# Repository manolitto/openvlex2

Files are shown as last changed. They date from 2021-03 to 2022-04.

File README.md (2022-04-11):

<p align="center">OpenVLex2 Showcase</p>
<h1 align="center">OpenVLex 2</h1>
<p align="center">A decor-to-base <b>V</b>ertical <b>L</b>ocking <b>ex</b>tension system for 3D printed terrain</p>
<p align="center">
  <a href="#about">About</a> •
  <a href="#download">Download</a> •
  <a href="#getting-started">Getting Started</a> •
  <a href="#faqs">FAQs</a> •
  <a href="#credits">Credits</a> •
  <a href="#license">License</a>
</p>

## About

OpenVLex makes it possible to print and use base and terrain parts more **flexibly** by providing a special vertical locking mechanism while still adhering to the widely used, well-established tile locking systems. You can use the same terrain decor piece with bases of different sizes or locking standards. Think OpenForge 2.0, but instead of gluing, you clip your terrain pieces to the base.  
For now, OpenVLex supports bases with **OpenLOCK (Triplex)** standard, and also the versatile **OpenForge Magnetic OpenLOCK** bases. Other locking systems (Dragonlock, Infinitylock) may be supported in the future.

OpenLOCK compatible

### What to expect

OpenVLex vertical locking can be used in many ways, but the most common use case is that you have versatile painted "wall on tile" (aka "wall on floor") terrain pieces that you want to reuse in multiple scenarios with different room sizes.

#### Key features:

- **Extend** the tile sets you already have. OpenVLex is **NOT yet another tile locking system**, but serves to make Magnetic/OpenLOCK tiles even more versatile.

- Magnetic bases are cool and handy, but not as versatile and not as solidly clipping together as Triplex parts: With OpenVLex you can **choose the right tile locking system "just in time"**.

- Large overhanging (upper) floors clipped together are not always as solid as they need to be. With OpenVLex you can build **rock solid upper floors** even with tiny 1x1 wall or corner pieces on up to 8x8 bases (or even larger if your printer is capable).

- With reusable OpenVLex magnetic bases, you need **much fewer magnetic balls** in total.

- OpenVLex **risers and stair parts** can be stacked and plugged together directly, giving you endless possibilities.

- OpenVLex gives you **dynamic floors out of the box**: each 1x1 floor tile can immediately be used for mosaics, patterned floors or as a scatter.

- With OpenVLex you can **re-use** your **wall-on-tile parts** (walls, floors, ...) on the **outside** of your dungeons or buildings without having ugly holes in the foundation.

- OpenVLex allows you to flexibly exchange the base of **"separate wall"** parts and make an **interior 1/2 inch** wide interior wall out of an exterior wall. This wall can be locked by using special 1/2 inch "through hole" clips.

- With a basic set of reusable bases in different sizes, you will never have to print a base again. **Save printing time and money**. And save plastic and rare earths (magnets). Save the planet! :earth_africa::earth_americas::earth_asia::nerd_face:

- OpenVLex is a non-commercial **open source** solution that I created in my spare time. Feel **free to use** it. No need to buy me a coffee or a beer, instead, just be a nice person and help people in need :relaxed:.  
  And please share your experiences with OpenVLex and give me feedback!

## Download

You can find the latest release [here](https://github.com/manolitto/openvlex2/releases/latest).

## Getting started

To give you an idea of how OpenVLex works and the advantages it offers, you can follow this guide:

1. Choose your favourite OpenForge 2.0 floor terrain set.  
   > If you are unsure, start with Devon Jones' well-known [OpenForge 2.0 Dungeon Stone Floor](https://www.thingiverse.com/thing:2740273)

2. Print **one** 1x1, **one** 2x2 and **four** 2x1 inch based (Dungeon Stone) floor parts.  
   Print only the decor parts without the OpenForge 2.0 bases!  
   > **Printing time:** ~3 hours at medium quality on a FFF printer
   
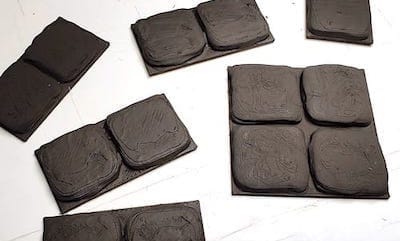
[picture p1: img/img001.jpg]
Floor tiles
   

3. Download [the latest version](https://github.com/manolitto/openvlex2/releases/latest) of OpenVLex 2 if you haven't already done so.

4. Print fourteen **[OpenVLex jacks](jacks/)**. See [jack printing details and hints](jacks/README.md).  
   > **Printing time:** < 40 mins
   
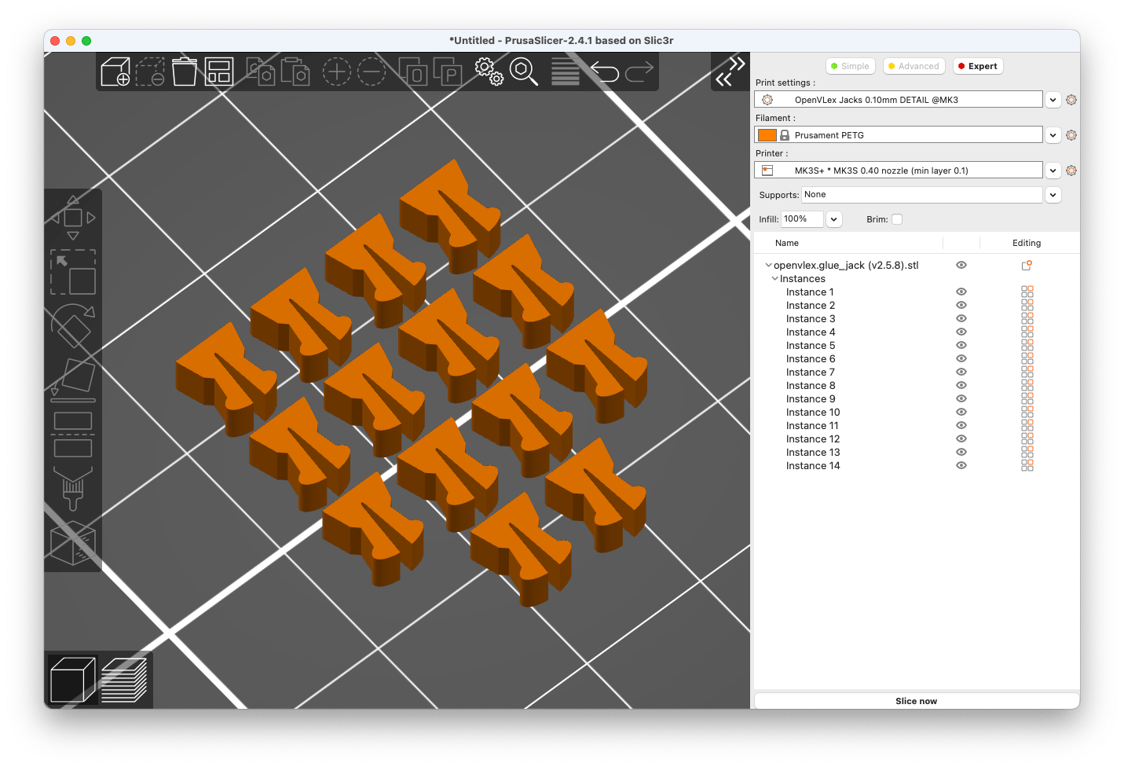
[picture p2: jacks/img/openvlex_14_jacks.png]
OpenVLex jacks
   

5. Glue the jacks to the floor parts. See [jack gluing instructions](jacks/README.md#gluing-instructions).  
   > **Note:** You only need thirteen jacks, one is a spare
   
   Either with a [gluing stencil](./gluing-stencil/README.md) (recommended)
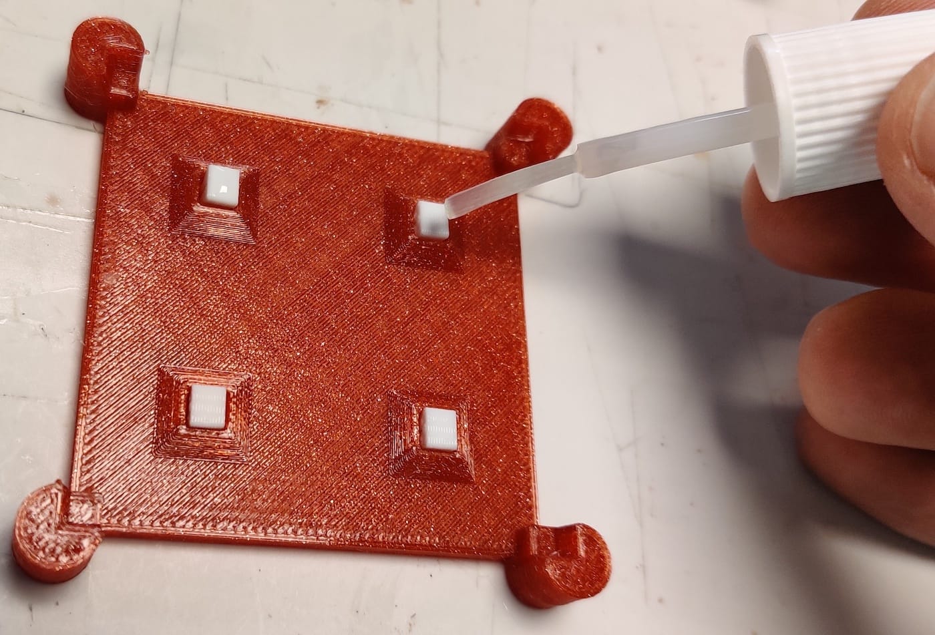
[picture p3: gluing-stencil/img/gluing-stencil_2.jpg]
   
   Or with an already printed [OpenVLex base](./bases/README.md)
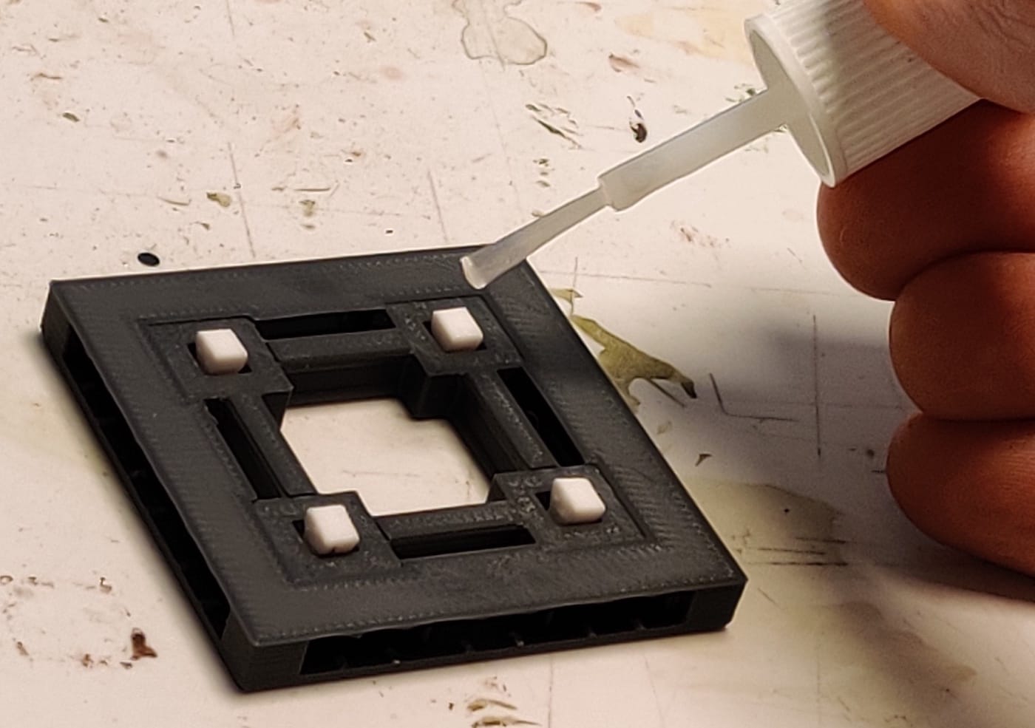
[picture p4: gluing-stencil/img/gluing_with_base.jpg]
   
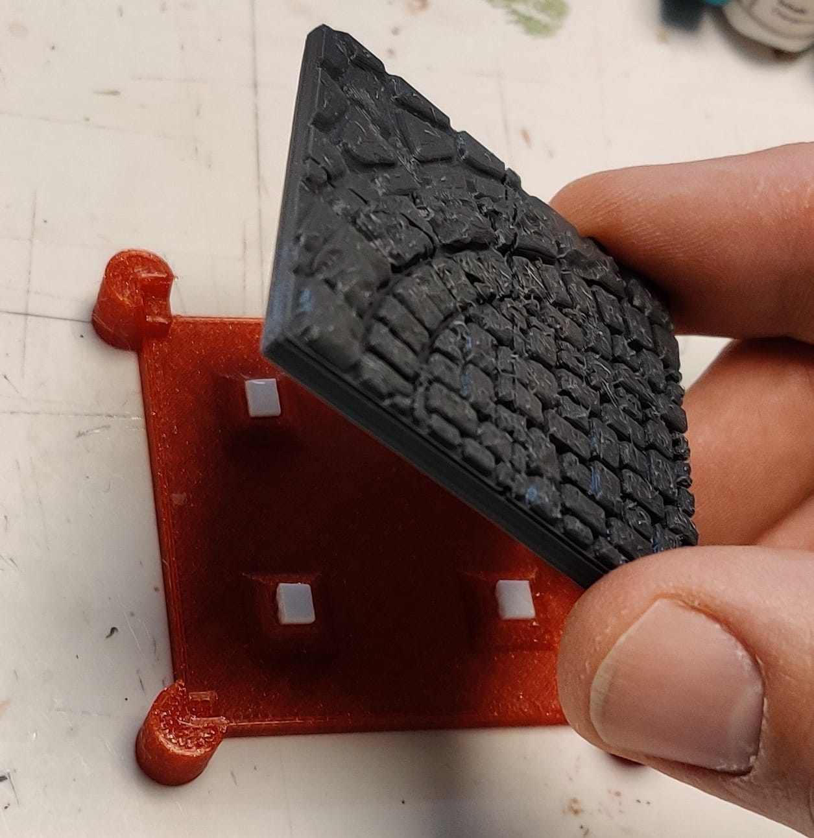
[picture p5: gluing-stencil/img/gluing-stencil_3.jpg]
     
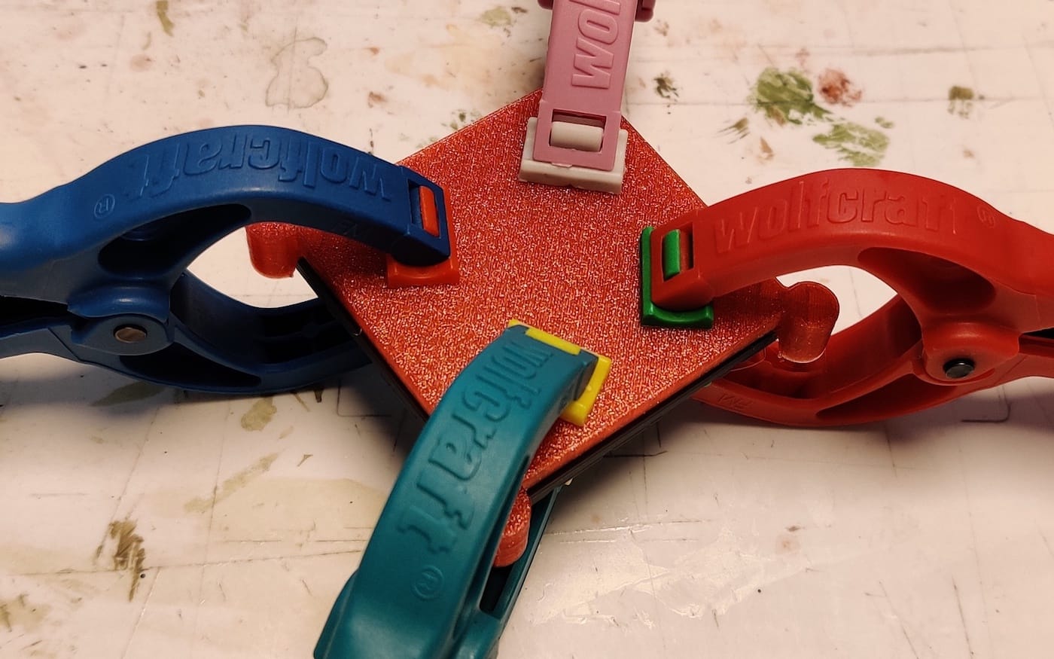
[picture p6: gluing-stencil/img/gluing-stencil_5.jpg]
     
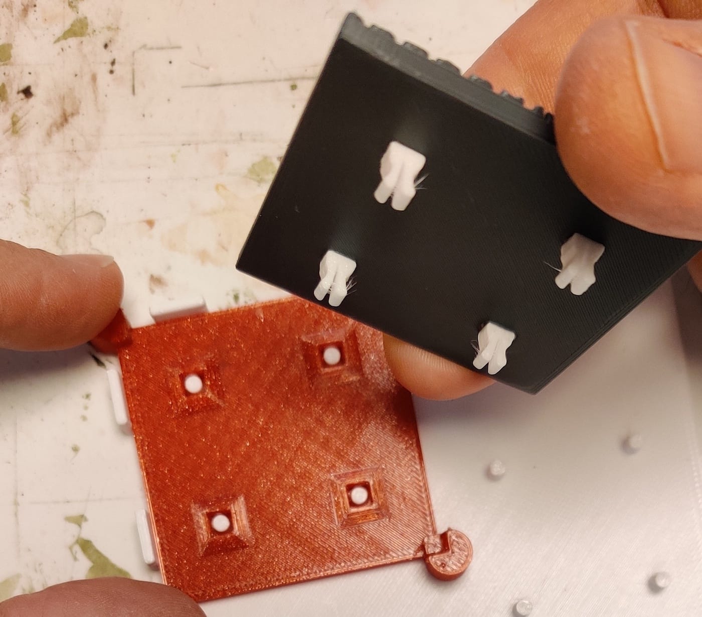
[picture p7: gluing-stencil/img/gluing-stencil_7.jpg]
     

6. Print out some **[OpenVLex Triplex bases](bases/plain/triplex/)** in the sizes you want. For now, print only one of each of your preferred sizes from the following list: 1x1, 2x1, 2x2, 3x2, 3x3, 4x1, 4x2, 4x3, 5x1, 5x2, 6x1, 6x2, 7x1, 8x1.  
   See [printing instructions for bases](bases/README.md).  
   > **Printing times:** 1x1 = ~20 mins, 2x2 = ~1 hour, 7x1 = ~2 hours
   
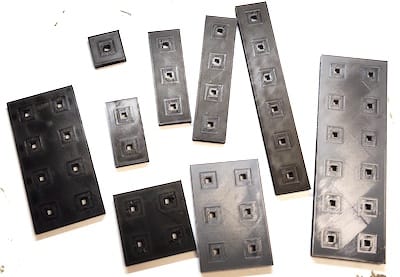
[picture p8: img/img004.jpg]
OpenVLex Triplex bases
   

7. **(Optional)** :man_artist: In the meantime, paint your floor parts. :woman_artist:

8. :thumbsup: **Done!**  
   Enjoy having **14 (fourteen!) different tile sizes** at your disposal with just six printed (and painted :pleading_face:) floor pieces!  
   
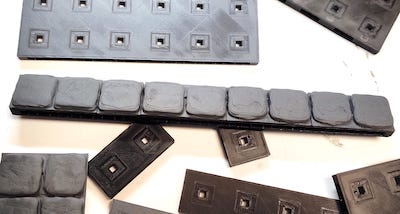
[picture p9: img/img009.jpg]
Finished pieces 1
     
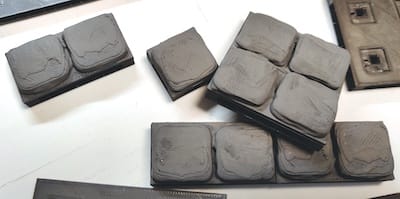
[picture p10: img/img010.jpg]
Finished pieces 2
     
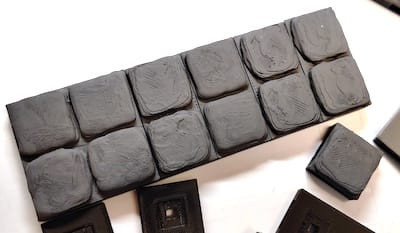
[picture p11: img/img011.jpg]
Finished pieces 3
     
   
   And look forward to even more flexibility! :astonished: Continue reading...

### Next steps

If you are either not yet convinced or already eager to learn more about the possibilities of OpenVLex, here are a few ideas and pointers:

- Print **other floor styles** (Cut Stone, Rough Stone, Towne, ...) in the common sizes 1x1, 2x1 and 2x2. Apply OpenVLex jacks and use them with your new OpenVLex bases in different sizes.  
  
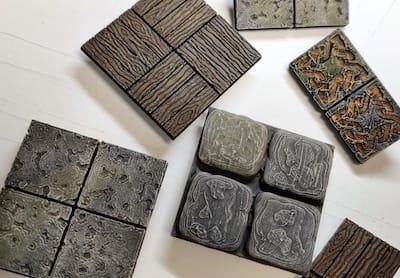
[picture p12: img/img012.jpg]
Other floor styles
  

- Print out some **[OpenVLex Magnetic bases](bases/plain/magnetic.openlock/)** (see [instructions](bases/README.md)) and use them as alternative (magnetic) bases for situations and scenes where you need more flexibility during play sessions.
     
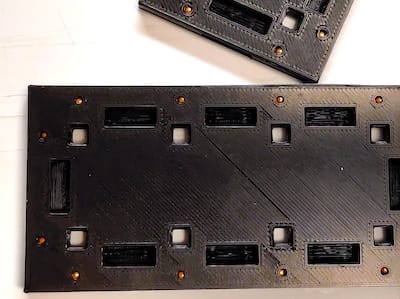
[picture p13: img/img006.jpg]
OpenVLex Magnetic bases
  

- Print out "wall on tile" **walls, corners and doors** and use OpenVLex to combine them with floors to create different sized tiles or even whole rooms.  
  
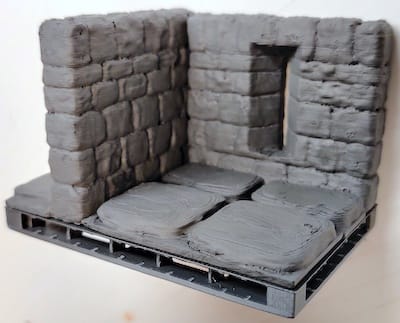
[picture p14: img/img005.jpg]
Walls
    
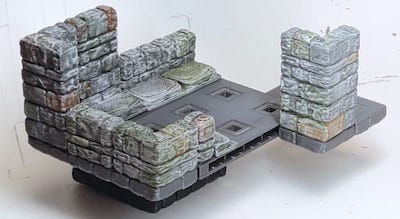
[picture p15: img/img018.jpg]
Walls and Bases
    
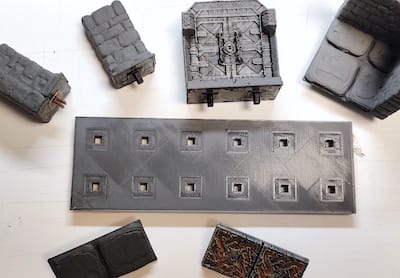
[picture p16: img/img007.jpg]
Corners
    
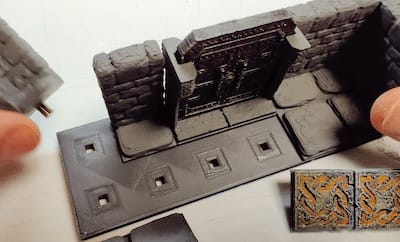
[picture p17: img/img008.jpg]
Doors
  

- Print some **[OpenVLex Riser and Stair remixes](stairs_and_risers/)**, apply OpenVLex jacks ...

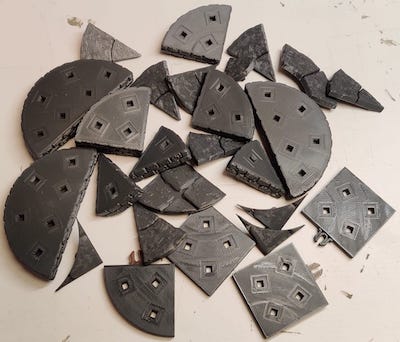
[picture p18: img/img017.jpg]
Disassembled Staircase
  
  
  ... and enjoy stacking and plugging the pieces together to build stairs and platforms in endless variety.
  
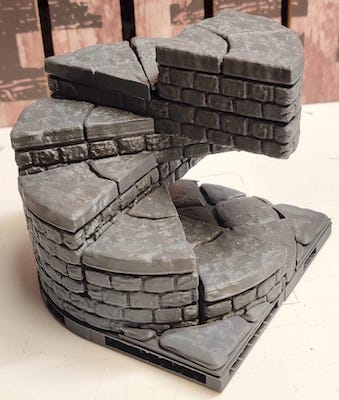
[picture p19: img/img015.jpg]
Spiral Staircase
  
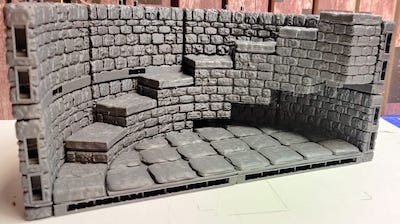
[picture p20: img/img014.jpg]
Tower Staircase
  

- Print a type "A" separate wall and use it either as an exterior wall with a textured base or as an interior wall by using the special [1/2 inch OpenVLex base](bases/separate_wall/).

- Print a bunch of 1x1 floor tiles of different styles (e.g. Dwarven Plain and Knotwork) and enjoy building **mosaics and patterned floor** tiles in endless variety.

- Print terrain and building parts from other systems and vendors (like OpenLOCK, DRAGONLOCK, Tilescape, ...) and combine them all with your new flexible OpenVLex bases. See FAQs below for instructions about preparing such parts.

- Build amazing dungeons and houses. Have fun! :star_struck:

## FAQs

**Question:** OpenForge walls and corners from the construction sets are normally glued to the base together with matching floor parts. How does this work with OpenVLex jacks?  

**Answer:** Print them together as one piece! Just put the pieces you want to combine together in your slicer. In Slic3r/PrusaSlicer/SuperSlicer it's pretty easy. I assume it is also possible in Cura, but I have never tried it.

---

**Q:** Sometimes larger floor tiles are difficult to detach and remove from the base. Any tips?

**A:** If using your fingernails :nail_care: is not an option :grimacing:, use flat-nose pliers to press the jacks together from the underside and carefully push them through. Or use a flat screwdriver to carefully and gradually spread the two parts apart from all four sides.

**New**: You may also consider using the new [disassembly tool](disassembly-tool/)!

---

**Q:** The jacks look fragile and I am sure I will manage to break one. I don't want to throw away painted tiles because of a broken jack!  

**A:** Rest assured that you don't have to! Try to remove the broken jack with pliers and a carpet knife (:warning: Watch your fingers! :face_with_head_bandage:). If the joint is too strong, put the tile into the freezer for some while. This makes the superglue brittle. (Thanks, Devon Jones, for this valuable hint!)

---

**Q:** Can I use terrain and building tiles from other systems and vendors with OpenVLex?

**A:** Yes, you can use whatever tile you want (as soon as it is based on some kind of modular grid system)! Simply cut away the bottom part of the tile (the part where the holes for the proprietary locking mechanism are). Most slicer applications already support cutting pieces horizontally, so you do not even need 3D software for this. Here are hints for some systems:

  - OpenLOCK terrain tiles: cut away and drop 6 mm from bottom
  - DRAGONLOCK:
    - Most Tile Sets: drop bottom 5.28 mm
    - Some Tile Sets: drop just 5.21 mm (the minimum DRAGONLOCK base height)
    - Shadowgrove Forest: cutting away 6mm from bottom works quite well
  - Tilescape: drop 6.4 mm from bottom of tiles with integrated frame, nothing to drop for frameless tiles

---

### What about OpenFLex 1?

The old OpenFLex 1 system is no longer maintained and I recommend switching to OpenVLex 2.

But wait, what if ...

- ... you already have a bunch of floor and wall tiles with **legacy plug plates** attached?  
  Simply put the tiles into the freezer for some while. This makes the superglue brittle and lets you easily remove the old plates with the help of pliers and a carpet knife (:warning: Watch your fingers! :face_with_head_bandage:). Then replace them with the appropriate number of OpenVLex 2 jacks.

- ... you already have a bunch of **legacy OpenFLex 1 base parts**?  
  Although you can convert them to the new standard with the [adapter](openflex1_to_openvlex2_adapter/README.md), I strongly recommend that you print new bases instead, reuse the magnetic balls and throw away or recycle the old bases.

- ... you already have some **expensively painted riser or stair parts** based on the legacy OpenFLex 1 system?  
  Do **not** throw them away! There is a way to make your old parts OpenVLex 2 compatible with [this special adapter part](openflex1_to_openvlex2_adapter/README.md).

## Credits

OpenVLex is based on OpenForge 2.0 by [Masterwork Tools](https://www.patreon.com/masterworktools/) and has been partially remixed from:

* [OpenForge 2.0 Wall On Tile Bases](https://www.thingiverse.com/thing:2740279)
* [OpenForge 2.0 Cut Stone Stairs](https://www.thingiverse.com/thing:1508410)
* [OpenForge 2.0 Dungeon Stone Stairs](https://www.thingiverse.com/thing:3393468)
* [OpenForge 2.0 Tudor Stairs](https://www.thingiverse.com/thing:1758162)

The OpenLOCK system was created by [Printablescenery](https://www.printablescenery.com/product/open-lock/).

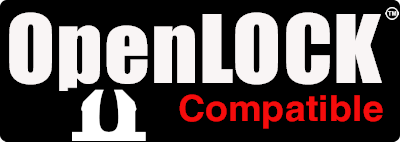
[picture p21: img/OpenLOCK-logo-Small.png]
OpenLOCK compatible


## License

<br /><span xmlns:dct="http://purl.org/dc/terms/" property="dct:title">OpenVLex 2</span> is licensed under a <a rel="license" href="http://creativecommons.org/licenses/by-sa/4.0/">Creative Commons Attribution-ShareAlike 4.0 International License</a>.

The OpenLOCK system is used under the BSD license: [Printablescenery OpenLOCK license](https://www.printablescenery.com/2021/03/17/openvlex-2/)

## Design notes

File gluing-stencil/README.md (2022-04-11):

# OpenVLex Gluing Stencils

## About

Stencils for easier and more accurate gluing of OpenVLex jacks onto the underside of tiles.

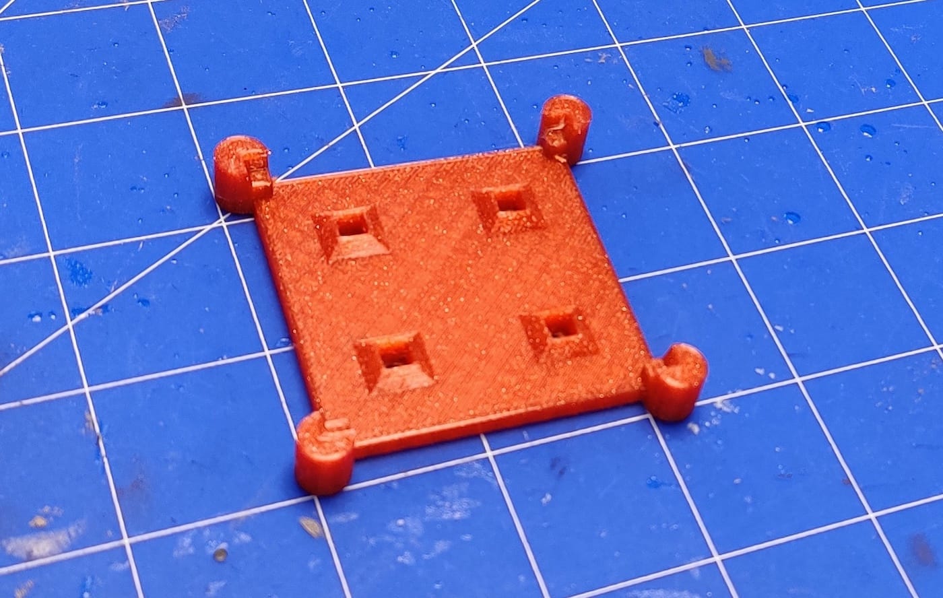
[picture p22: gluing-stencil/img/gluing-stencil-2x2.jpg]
Gluing Stencil
    

## Instructions

As a basic set, print one 1x1, one 2x1 and one 2x2 stencil. This should cover 90% of your OpenVLex tiles. Remember that the purpose of OpenVLex is to prevent the need for exotic tile sizes.

## Usage

### 1. Place the jacks

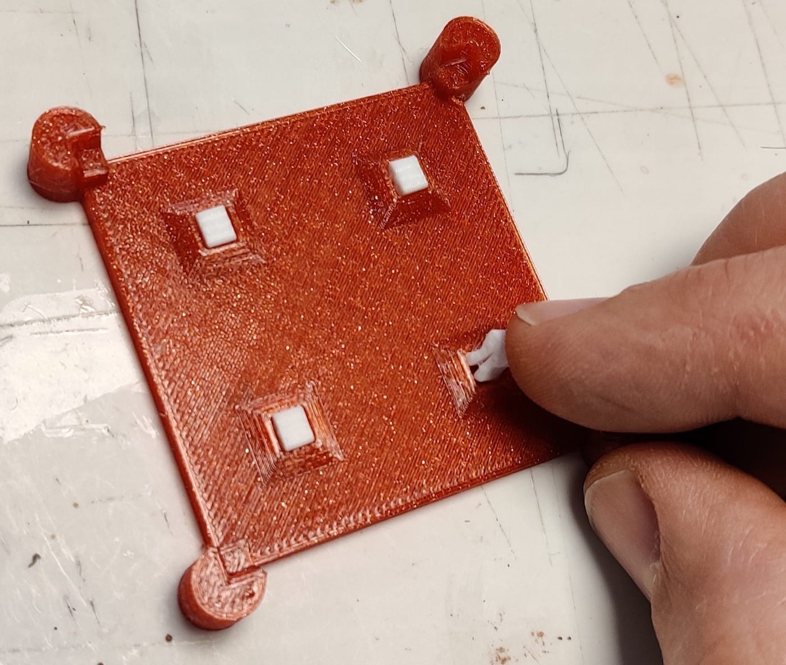
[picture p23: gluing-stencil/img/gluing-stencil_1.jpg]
Gluing Stencil - Place the jacks
    

### 2. Put glue on the jacks

   Gluing Stencil - Put glue on the jacks 

### 3. Place the tile

   Gluing Stencil - Place the tile 
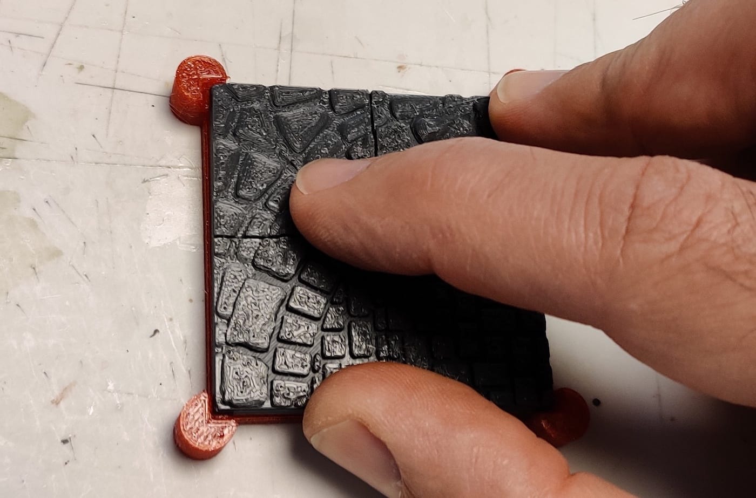
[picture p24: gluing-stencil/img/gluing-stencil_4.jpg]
Gluing Stencil - Place the tile
    

### 4. Use clamps until glue is dry (but not too long)

   > **Note:** Keeping the parts upside down during drying prevents glue from dripping onto the stencil

   Gluing Stencil - Use clamps 

### 5. Place stencil on [disassembly plate](../disassembly-tool/README.md) and push down corners

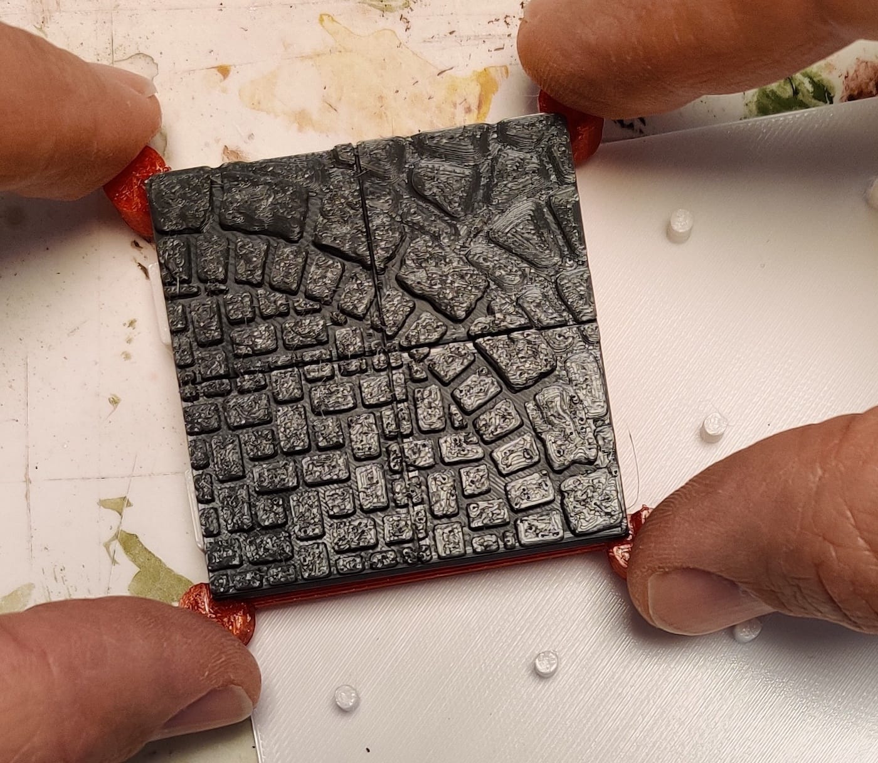
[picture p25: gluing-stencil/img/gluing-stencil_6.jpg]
Gluing Stencil - push down corners
    
   Gluing Stencil - removed 

### 6. Use your tile in the most VLexible ways

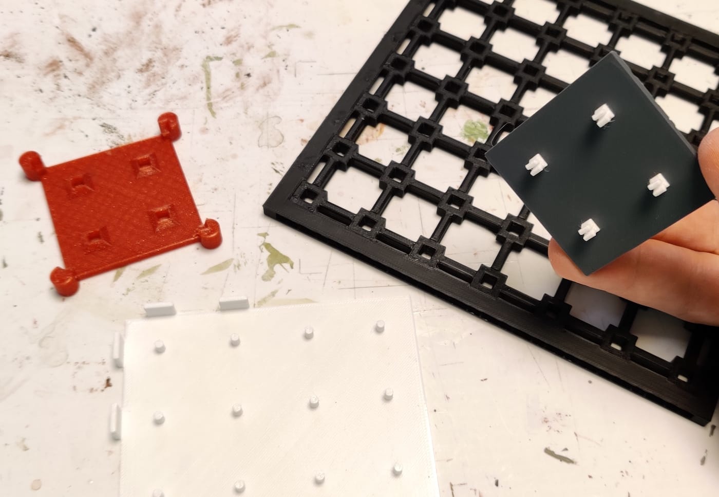
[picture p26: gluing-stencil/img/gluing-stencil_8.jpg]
Gluing Stencil - usage 1
    
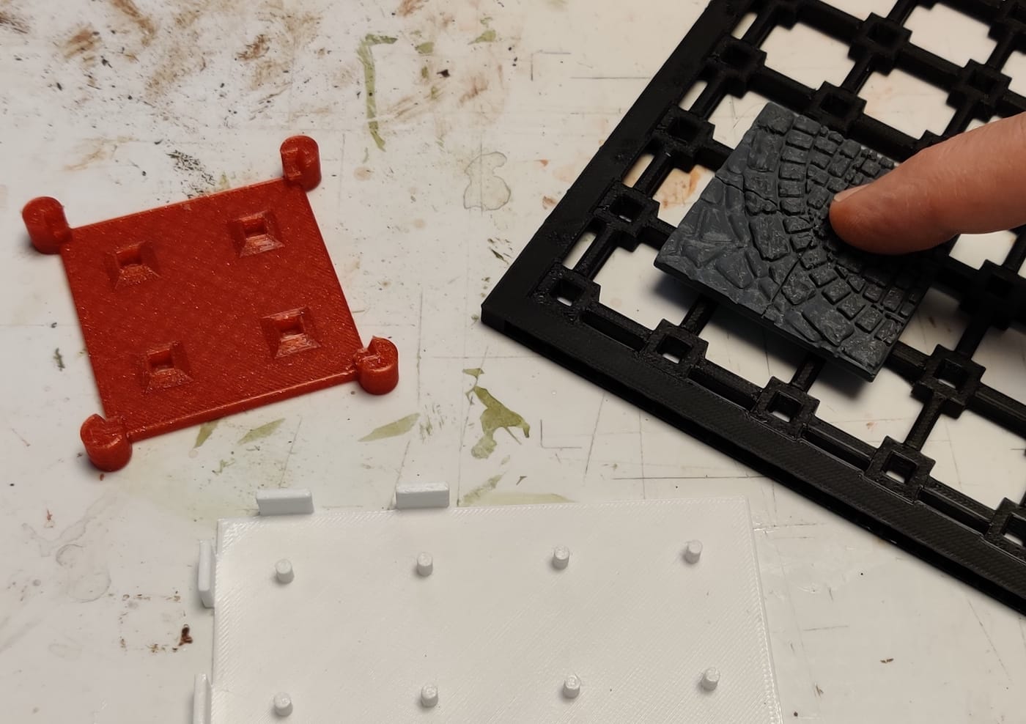
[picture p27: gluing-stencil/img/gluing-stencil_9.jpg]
Gluing Stencil - usage 2
    
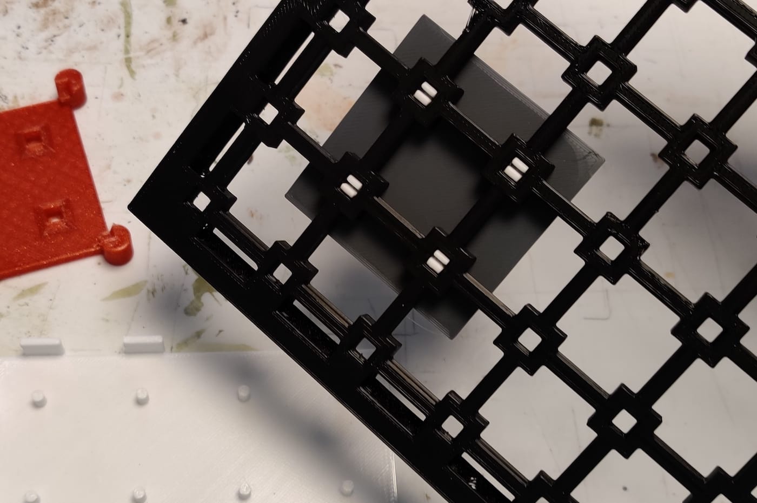
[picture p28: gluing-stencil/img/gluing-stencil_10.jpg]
Gluing Stencil - usage 3
    
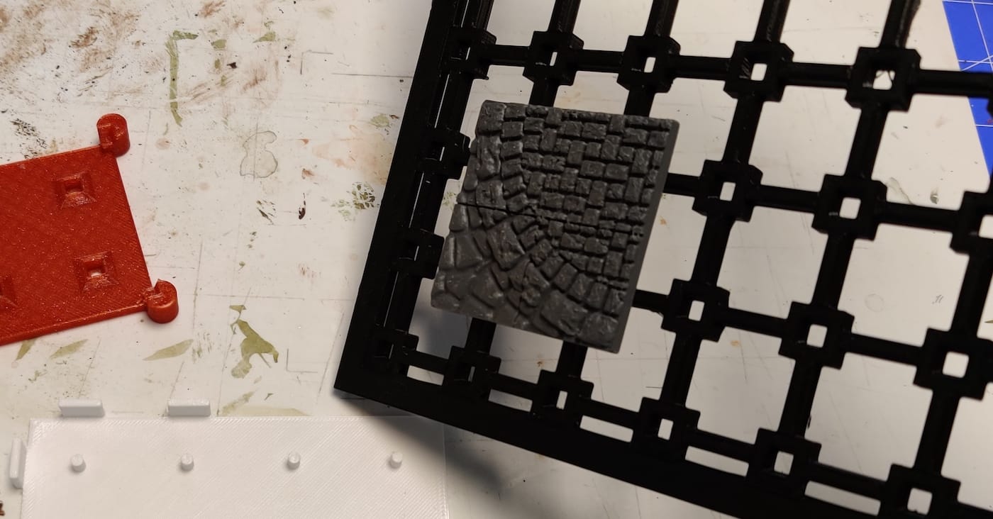
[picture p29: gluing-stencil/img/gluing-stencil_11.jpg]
Gluing Stencil - usage 4
    

## Printing Notes

- Material: PLA or PETG
- Nozzle: 0.4 mm
- Layer height: 0.10 mm or 0.15 mm
- Fill Density: 10% to 15%

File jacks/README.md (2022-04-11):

# OpenVLex Jacks

## About

OpenVLex jacks are used to vertically clip parts together. One or both of the parts must have an OpenVLex socket hole were the jack snaps in. There are two ways of clipping parts together:

1. Socket hole(s) on the lower part and standard jacks glued to the bottom surface of the upper part.

2. Socket hole(s) on both the lower and the upper part and a double-jack that clips them together.

## OpenVLex Standard Jacks

OpenVLex jacks are glued to the underside of "wall on tile" floor/wall tiles or risers (those without holes on the bottom side). Attach one jack per inch grid field. There is a printable stencil that makes gluing much easier and faster - see [gluing instructions](#gluing-instructions) below.

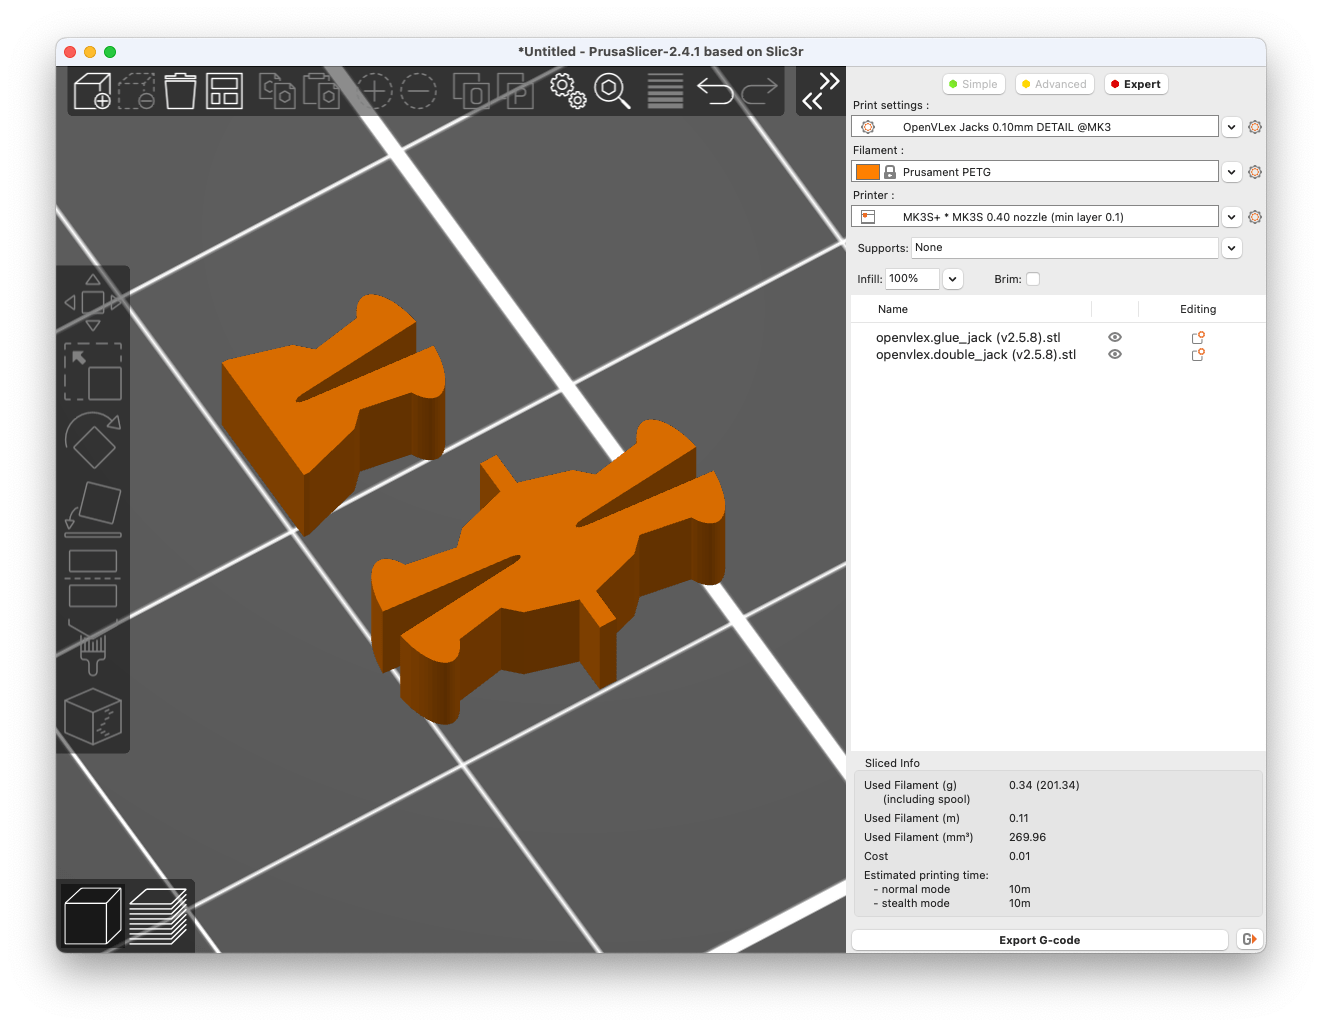
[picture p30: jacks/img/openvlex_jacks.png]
OpenVLex Jacks

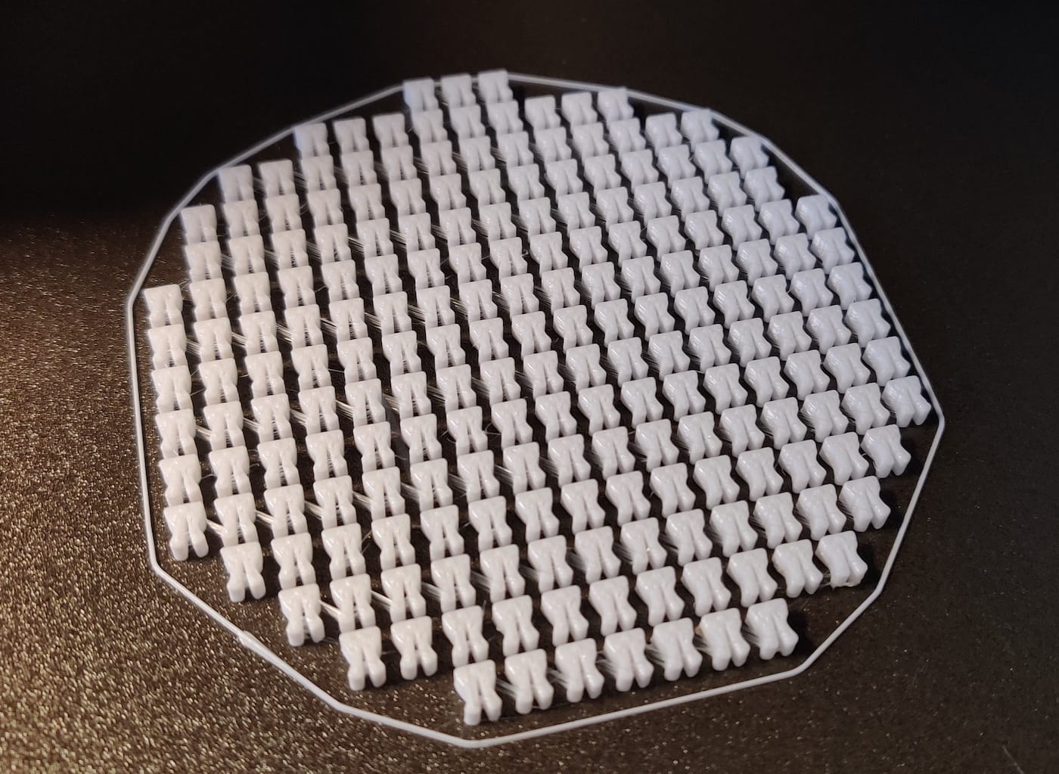
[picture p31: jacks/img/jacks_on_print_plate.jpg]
OpenVLex Jacks

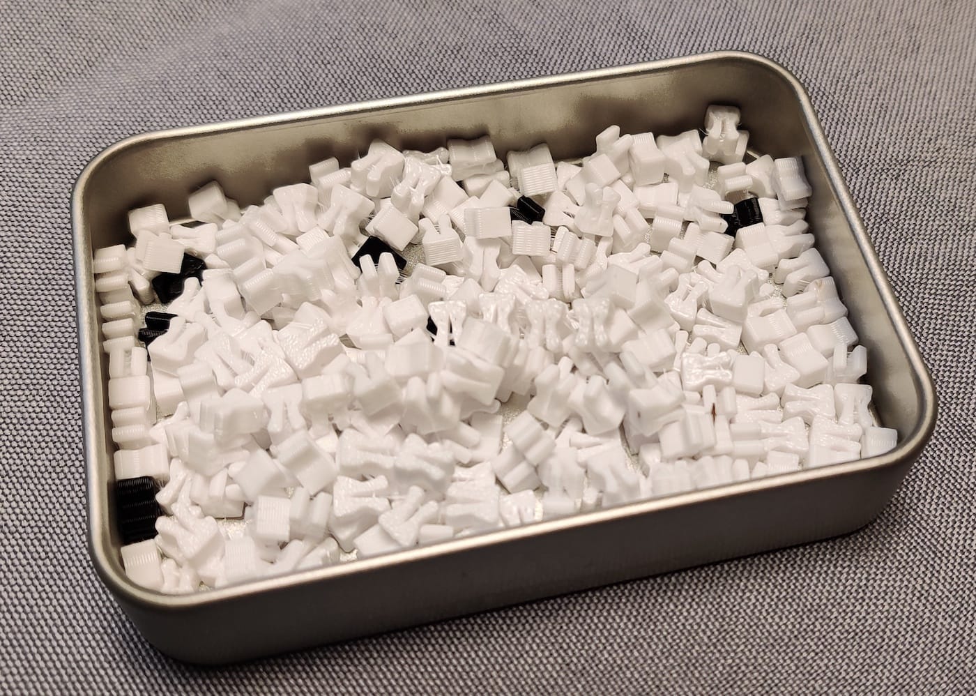
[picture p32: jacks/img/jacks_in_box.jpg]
OpenVLex Jacks


### Gluing Instructions

- The recommended way to glue OpenVLex jacks to your tiles is to use one of the [gluing stencils](../gluing-stencil/README.md). However, for just trying out and testing OpenVLex you do not need a stencil yet, just use an already printed OpenVLex base as a stencil.  
  
  Glue jacks to floor parts

- Align the jacks of one tile so that they all have the same direction. This makes it easier to unplug the upper part later.

- For wall tiles and non-square floor tiles (e.g. 2x1), it is advisable to align the sockets so that the "slot" of the jack points towards the wall or the longer tile side. It is then much easier to unplug the tile by wiggling it slightly.

- Use **superglue**, which allows the tile to be used immediately after a few minutes. And in case a jack breaks one day it's easy to remove and replace it: put the tile into your freezer for a while and remove it with a carpet knife.

  Glue jacks to floor parts
  Glue jacks to floor parts
  Glue jacks to floor parts

- Use clamps to press the pieces firmly together until the glue is dry and strong enough.

   > **Note:** Keeping the parts upside down during drying prevents glue from dripping onto the stencil

  Glue jacks to floor parts

- Carefully remove the tile from the stencil. You can also use a flat screwdriver to carefully lift the tile or push the jacks through from the underside.

- You may also consider using the [disassembly tool](../disassembly-tool/README.md) for easily removing the tile from the stencil.

  Glue jacks to floor parts

## OpenVLex Double Jacks

Use double jacks to vertically clip together OpenVLex parts (risers and stairs) that have holes on the bottom side.

Double Jacks

## Printing Notes for OpenVLex Glue Jacks

> **Please note:** If you are completely new to 3D printing, please expect some challenges. I'm **not** saying you shouldn't try, it also depends a lot on the quality and capacity of your printer and the material. However, as these are tiny little things to print, you should have your **first layer** lessons learned.

- Material: PLA or PETG (recommended)

- Nozzle: 0.4 mm (or smaller)

- Layer height: 0.10 mm (recommended), 0.15 mm, 0.20 mm

- Fill Density: 100% (actually should not matter)

The jacks are quite small parts, so the most important issue is the adhesion of the first layer - as always with FFF printers. If you experience difficulties, you can try the following measures **after** you have fine-tuned your z-height:

1. **Lower** first layer **speed**
2. **Clean bed** with IPA
3. **Clean bed** with acetone (if using a PEI sheet)
4. Use **brims**
5. Raise **bed temperature** (slightly!)
6. Raise (or lower) **hotend temperature**
7. Try **different materials** - my recommendation is to use a not too brittle PLA or PETG!

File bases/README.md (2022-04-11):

# OpenVLex 2 Bases

## About

OpenVLex bases can be used as universal bases for all your "wall on tile" terrain pieces. They can be used side by side with all your existing and your "separate wall" OpenForge and OpenLOCK tiles.

### Locking Systems: OpenLOCK, Triplex, Dragonlock

OpenVLex currently supports three different locking variants:

- "openlock,magnetic" - combination of single centered OpenLOCK holes and holes for magnetic spheres (or discs)
- "openlock" (formerly known as "triplex") - with or without additional "braces" structure (see below)
- "dragonlock" - early state / proof of concept

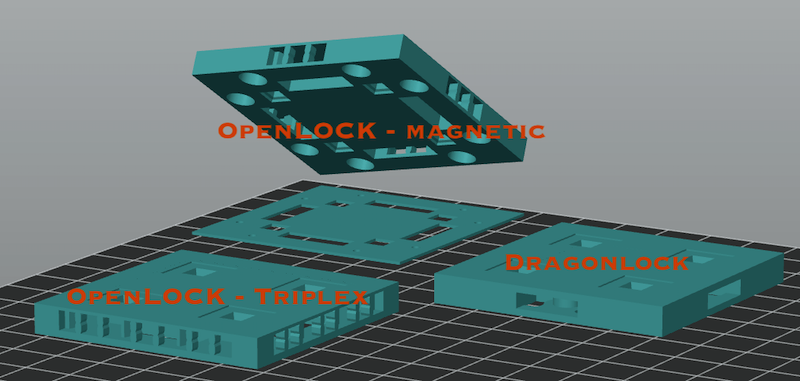
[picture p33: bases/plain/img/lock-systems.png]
Locking Systems
   

### Geometry: square, curved and radial

Most of the time you will need bases with "square" base area shape and "square" OpenVLex sockets geometry. When it comes to **curved** floors, stairs, or risers you will switch to "curved" base areas and "radial" sockets.

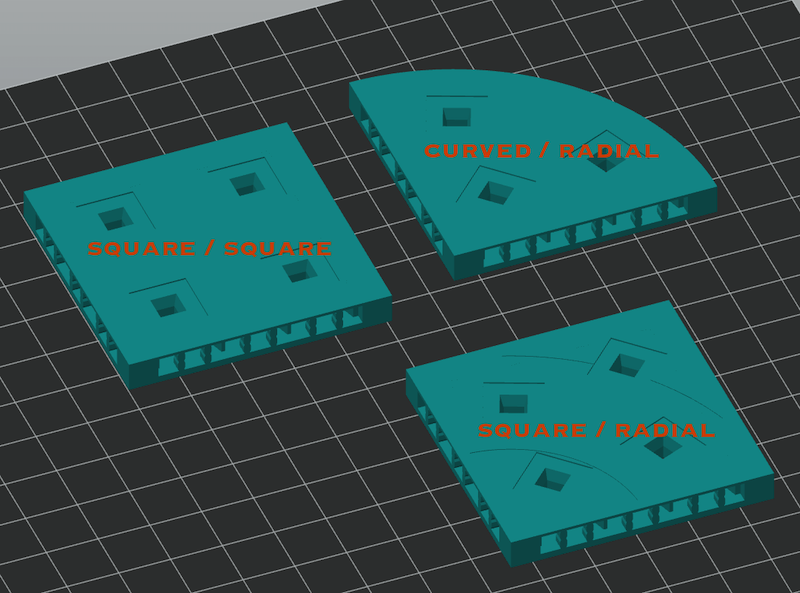
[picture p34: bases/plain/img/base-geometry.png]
Base Geometry
   
   
### Style

In addition to "plain" bases there are plans to add corner and edge bases in different styles. "Dungeon Stone" is the first supported OpenVLex base style.

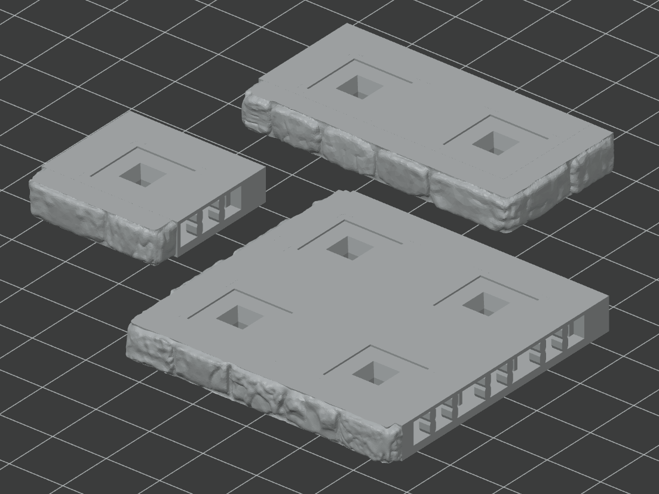
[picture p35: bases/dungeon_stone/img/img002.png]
Dungeon Stone bases - 3D
   
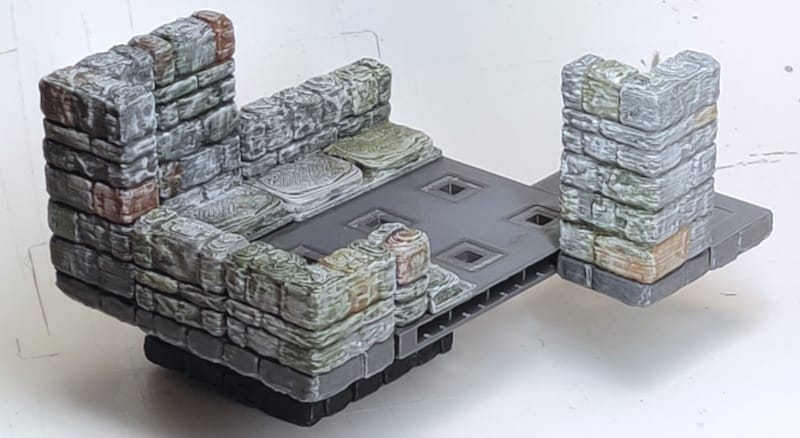
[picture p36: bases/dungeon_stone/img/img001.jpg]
Dungeon Stone bases - Sample
   

## Instructions

### Magnetic OpenLOCK Bases

There are two ways to enclose the magnetic balls inside the base: print with pause or glue two parts.

#### Option 1: Magnetic OpenLOCK Bases - upper and lower parts glued together

If you are new to FDM printing or your slicer/printer does not support printing with a pause, follow these instructions for printing two parts that have to be glued together after inserting the magnets:

1. Print one lower part and one upper part of your chosen size.

   The files are named like this:
   - <code>plain#base+square.[W]x[L].magnetic,openlock,openvlex+lower_part</code>
   - <code>plain#base+square.[W]x[L].magnetic,openlock,openvlex+upper_part</code>

2. Turn the upper part over and insert 5 mm magnetic balls (or similar magnetic discs) into the round holes of the upper part.

3. Apply (super) glue, but be careful not to soil the magnetic balls.

4. Apply the bottom part and press the parts together. I recommend using clamps.

#### Option 2: Magnetic OpenLOCK Bases - print with pause

Important note: Please make sure that your FDM printer currently is equipped with a **brass nozzle**. Never try this with a steel nozzle - the magnets will get catched and you might damage your printer. Use at your own risk!

I also recommend **testing** this first with a very **small 1x1 base** to make sure the pausing works as expected. Some printers have issues with pausing by G-Code, especially when used with remote controlling software like OctoPrint.

1. Open the STL of the chosen size in your slicer (PrusaSlicer recommended).
   
   The files are named like this: <code>plain#base+square.[W]x[L].magnetic,openlock,openvlex+single_part.stl</code>
   
2. Add a pause print command at layer height 5.7 mm. Please google the exact method to achieve this with your slicer and printer!

   When using PrusaSlicer with a Prusa MK3 printer this would be the M601 command:

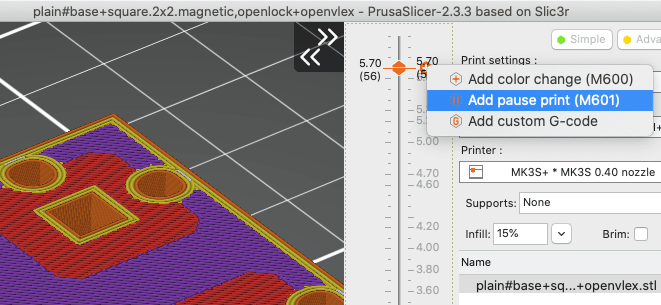
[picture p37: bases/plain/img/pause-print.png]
Insert pause example with PrusaSlicer
   

3. Start the print and when the print is paused, place the magnetic spheres inside the holes.
4. Resume the print

### OpenLOCK "Triplex" Bases have additional braces

> **Note:** These bases have additional tiny bars at the back wall of the triplex openings. They are NOT meant as removable
> printing support, they are small enough to not interfere with the OpenLOCK clip, and you do **NOT** need to **remove** them.

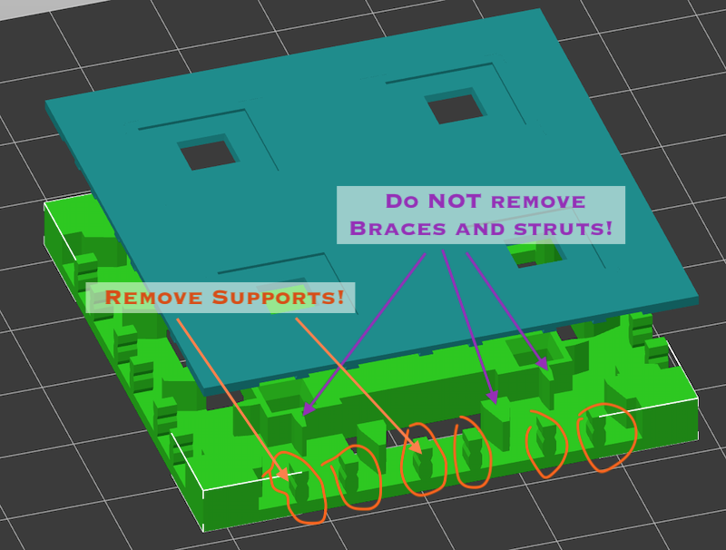
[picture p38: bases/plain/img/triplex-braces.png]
Triplex Braces
   

## Printing Notes

- Material: PLA or PETG
- Nozzle: 0.4 mm
- Layer height: 0.10 mm or 0.15 mm
- Fill Density: 10% to 15%

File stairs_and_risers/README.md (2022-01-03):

# OpenVLex 2 Stairs and Risers

## About

OpenVLex stairs and risers can be stacked and combined in endless variations.

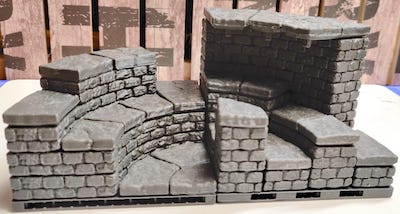
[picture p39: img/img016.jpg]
Crazy Risers and Stairs
  
  Spiral Staircase
  Tower Staircase

## Instructions for the new OpenVLex Plain Riser Stacking System

See separate [OpenVLex Plain Riser Stacking System instructions](plain/README.md)

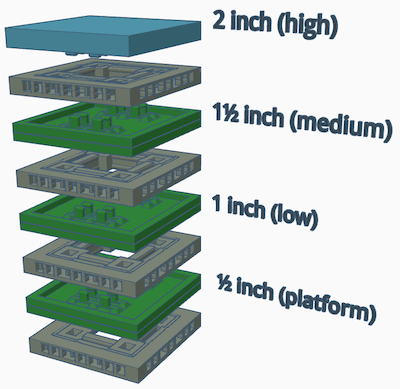
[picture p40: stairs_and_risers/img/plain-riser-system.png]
Plain Riser System
  

## Instructions for textured risers and stairs

### Height Variations

OpenVLex stairs and risers are available in different heights:

- 1/3" risers/stairs
- 1/2" risers/stairs
- 1" risers/stairs
- 1½" risers/stairs

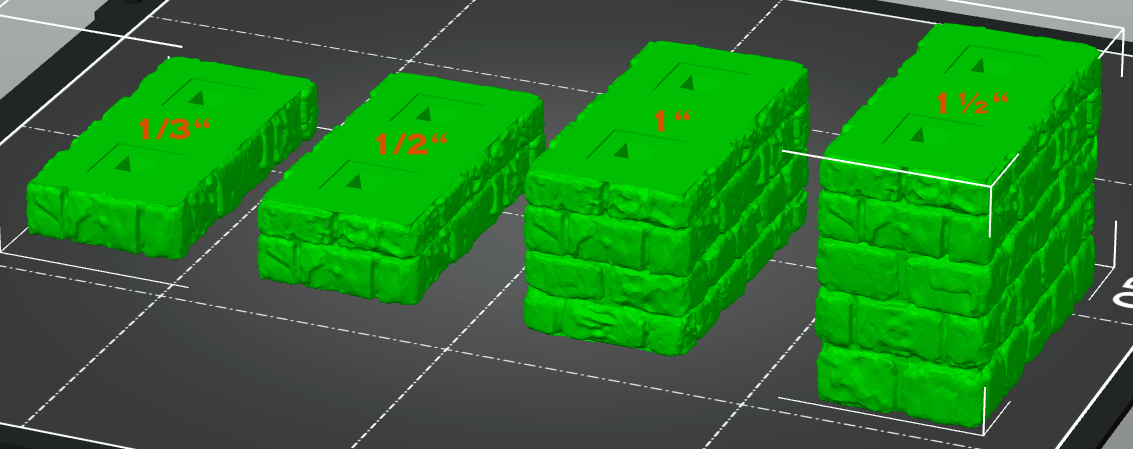
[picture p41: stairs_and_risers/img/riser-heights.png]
Riser Heights
  

- platforms to be used as top for risers/stairs

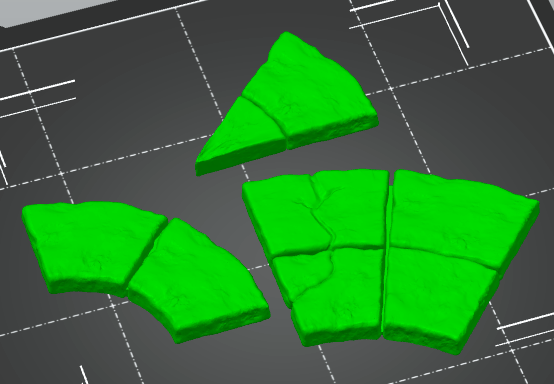
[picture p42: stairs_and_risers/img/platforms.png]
Platforms
  

- "riser bases" combine a riser and the base for the next level:
  the compass direction in the file name describes where the locking sides are: NE means side locks north and east

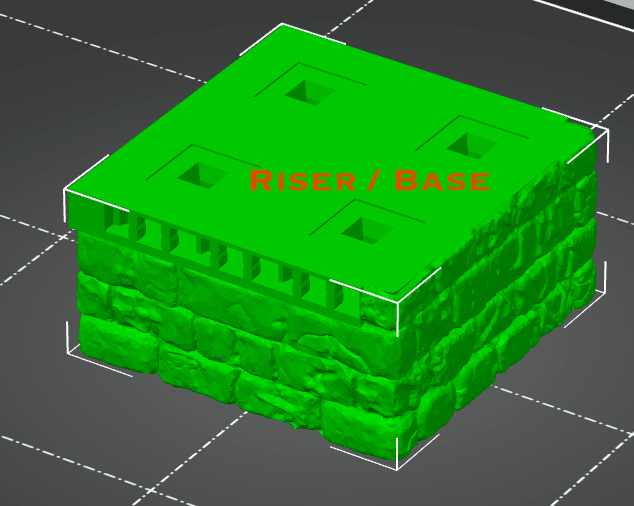
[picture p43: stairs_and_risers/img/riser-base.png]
Riser Base
  

### Clipping Variants

- For parts **without holes on the bottom** side (1/3" risers and platforms): print out [OpenVLex glue jacks](../jacks#openvlex-glue-jacks) and attach (i.e. glue) them to the bottom.

  Hint: Use another part of the same shape as a gluing stencil.

- For parts **with holes on the bottom** side ("openvlex.top\_and\_bottom"): print out some [OpenVLex double jacks](../jacks#openvlex-double-jacks) ("half strong" variant recommended) and use them to clip parts together **without gluing**.

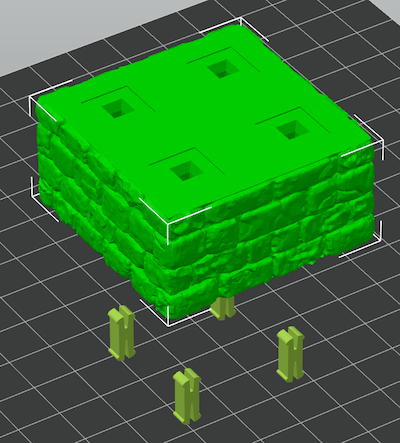
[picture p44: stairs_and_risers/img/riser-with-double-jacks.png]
Riser with Double Jacks
  

### Printing Notes for Stairs and Risers

- Material: PLA or PETG
- Nozzle: 0.4 mm
- Layer height: 0.10 mm or 0.15 mm
- Fill Density: 10% to 15%

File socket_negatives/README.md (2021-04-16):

# OpenVLex Socket Negatives

## About

With the socket negatives you can remix and kitbash other 3D part (your custom ones or from other sets) to make them
vertically stackable and clipping together with OpenVLex jacks.   

## Remix your own risers, stairs or stackable walls

- use "top socket negatives" for the top surface of risers

- use "bottom socket negatives" for the bottom of parts if you want to make them stackable with double jacks

- use "square/square" negatives for square and rectangular parts

- use "curved/radial" negatives for curved parts

## Instructions

- use the boolean tool of your favorite 3D mesh software to cut out top or bottom socket holes  

- vertically align top socket negatives to the top of your piece

- horizontally center align connector negatives to the inch grid

- for curved/radial sockets there are versions with a plate at z -100 mm which is meant to easier align the sockets to your custom part

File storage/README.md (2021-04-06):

# OpenVLex Storage Clips

## About

Use storage clips to convert your OpenVLex bases to storage racks. 

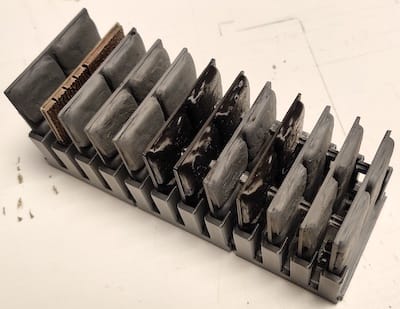
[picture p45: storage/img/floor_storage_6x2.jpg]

loose jack

## Instructions

Print two storage base clip parts and use them with a 2x2 (or larger) base to vertically store four floor tiles.

loose jack
loose jack

### Printing Notes

- Material: PLA or PETG
- Nozzle: 0.4 mm
- Layer height: 0.20 mm
- Fill Density: 20%

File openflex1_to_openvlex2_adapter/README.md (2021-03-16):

# OpenFLex 1 to OpenVLex 2 Adapter

## Instructions

- Print an adapter plate for each OpenFLex 1 tile you want to upgrade. Two sizes are provided. The smaller one is for upgrading risers, the larger one is for upgrading legacy bases (if you really want to).

- Print adapter sockets for each legacy socket on your tiles that you want to upgrade.

- Glue the adapter pieces onto your tile (see below)

### Printing Notes

- Material: PLA
- Nozzle: 0.4 mm
- Layer height: 0.10 mm
- Fill Density: 0% (should not matter)

See [printing notes for jacks](../jacks/README.md) if you experience issues with the first layer.

### Gluing and Cutting Notes

1. Apply superglue to the sides and bottom edges of your old socket holes.  

2. Push the adapter socket into the hole.

3. Repeat the procedure for each socket hole in your tile.

4. Let the glue dry.

5. Use a carpet knife to cut away the support rings.

6. Attach the adapter plate with glue.

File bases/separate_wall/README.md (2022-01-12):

# OpenVLex 2 Separate Wall Bases

## Story

Here is the story:
Once upon a time. Just a good old 1/2 inch wide separate towne wall used as exterior wall...

Good old separate towne wall

"So far, so good. And then?"

"Look whats happening!"

Plop!

<< plop! >>

Snap!

<< snap! >>

"Today I feel like I need a 1/2 inch interior wall!"

Snap!

"... which I now have together with that fantastic 1/2 inch _through hole_ clip !"

## Instructions

1. Print an OpenForge separate wall with taxonomy "A" from one of the following sets:

	- OpenForge Towne
	- OpenForge Cut Stone

2. Print one plain OpenVLex base: `plain#base.A.openlock,openvlex.stl`
3. Print one base which matches the wall style:

	- `towne#base.A.openlock,openvlex.stl`
	- `cut_stone#base.A.openlock,openvlex.stl`
	- `rough_stone#base.A.openlock,openvlex.stl`

4. Print two OpenVLex jacks
5. Glue the jacks to the bottom side of the wall. Use the plain OpenVLex base as a template.
6. As soon as the glue is dry carefully remove the wall from the base.
7. For now enjoy having two different bases for the same wall (one plain, one with texture) but do not stop here!
8. Download this special [OpenLOCK Clip Variants](https://www.drivethrurpg.com/product/325812/OpenLOCK-Clip-Variants) set.
9. Print the `OpenLOCK Half Inch Clip.stl`
10. Enjoy using your separate wall now as an interior wall by using that special "through hole" clip.

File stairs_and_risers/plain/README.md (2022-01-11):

# OpenVLex Plain Riser Stacking System

## About

The new OpenVLex stackable riser system makes it possible to stack risers of any [OpenForge risers](https://mmf.io/o/192663) compatible height by simply snapping them together.

  Plain Riser Stacking System

Simply reuse standard OpenVLex bases (>= v2.4) together with "snappy" interlayer parts (green) or platform parts for the top most layer (blue).

### Save material and be flexible!

  Plain Riser - Saving Parts and Material

In the picture above a 2x4 medium riser is built just from three standard OpenVLex bases (grey) with four 2x1 riser interlayers (green) and two 2x2 riser platforms (blue).

## Instructions

### Platform Riser

Simply print one piece of `plain#riser+square,platform.1x1.openvlex.stl`, `plain#riser+square,platform.2x1.openvlex.stl`, or `plain#riser+square,platform.2x2.openvlex.stl` and enjoy the snapping when applied to an OpenVLex 2.4 base!

  Platform Riser
  
☝️ Did you notice that this blocks can be plugged upon an OpenVLex 2.4 base from the top and also from the bottom?! Read on to learn why this is important.

### Low, Medium, and High Riser

For raising a base by ½ inch on top of another base, print two interlayer pieces (`plain#riser+square,interlayer_half.2x1.openvlex.stl` or `plain#riser+square,interlayer_half.2x2.openvlex.stl`) and glue them together at the flat plain sides like shown in this picture:

  Low, Medium, and High Riser - gluing
  
By combining several Interlayer Risers together with a Platform Riser and OpenVLex bases you can build every possible riser height. See pictures on top of this page.

### Platform 1x1 Riser

Simply print one piece of the 1x1 platform riser (`plain#riser+square,platform.1x1.openvlex.stl`) and plug it into a standard 1x1 OpenVLex base (`plain#base+square.1x1.openlock,openvlex.stl`).

  Platform 1x1 Riser - gluing

### Low, Medium, and High 1x1 Riser

The new OpenVLex secondary vertical locking system cannot be used for 1x1 parts because there is no space left for that second locking mechanism. Instead, special 1x1 risers are provided which use the standard OpenVLex socket to give "plug-and-play" risers.

For an [OpenForge plain riser](https://mmf.io/o/192663) compatible low riser, print two pieces of the 1x1 platform riser (`plain#riser+square,platform.1x1.openvlex.stl`) and two standard 1x1 OpenVLex bases (`plain#base+square.1x1.openlock,openvlex.stl`). Glue **one** riser and **one** base part together as shown in the following picture:

  Low, Medium, High 1x1 Riser
  
For medium and high risers, create multiple glued together 1x1 platform risers and standard 1x1 OpenVLex bases. You can then stack them to the height you need by simply plugging them together.

There is also a ready-to-use 1x1 low riser (`plain#riser+square,low.1x1.openvlex.stl`) which can be used as an alternative to the glued+plugged low riser.

### 1/2" Support Riser aka "Façade Level Riser"

This special half inch high support blocks can be plugged into the bottom of OpenVLex 2.4 bases which can then be placed upon (2 inch high) interior walls and thus lift them to a height which matches the 2½ inch high [OpenForge Façade](https://mmf.io/o/139980) parts. See blue block in sample picture below:

  1/2" Support Riser
  
These blocks are also useful in corners to hold the upper level in place and the upper façade aligned with the lower one.

### Low Riser used as "Roof Level Support Riser"

This special support blocks can be plugged into the bottom of OpenVLex bases bridging an attic floor between opposite [OpenForge Nx1.0 Shingles](https:mmf.io/o/135887). See blue block in sample picture below:

  Roof Level Support Riser

Like the Façade Level Support Risers (see above) these blocks are also useful when put in attic corners to hold the upper level in place and the roof aligned with the façade tiles below.

### Printing Notes for Plain Risers

- Material: PLA or PETG
- Nozzle: 0.4 mm
- Layer height: 0.10 mm
- Fill Density: 10% to 15%

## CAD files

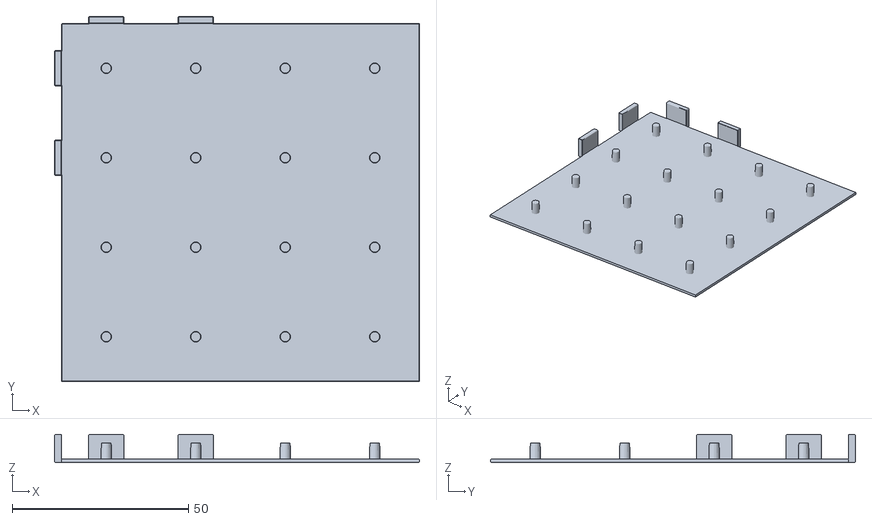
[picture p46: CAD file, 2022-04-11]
disassembly-tool/openvlex-disassembly-tool.4x4.stl
103.6 x 103.6 x 8.00

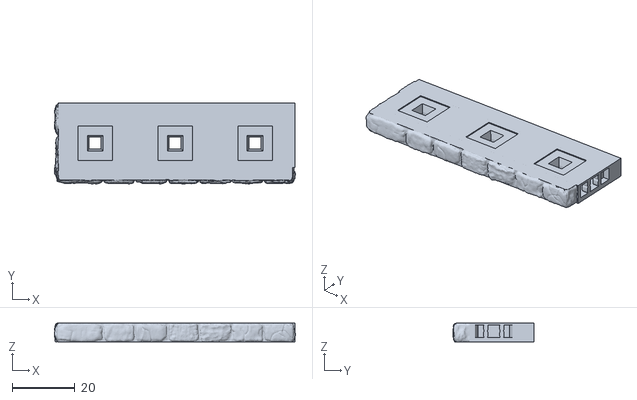
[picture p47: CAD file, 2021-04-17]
bases/dungeon_stone/dungeon_stone#base+square.3x1.openlock,openvlex+corner-left.stl
76.5 x 25.6 x 6.01

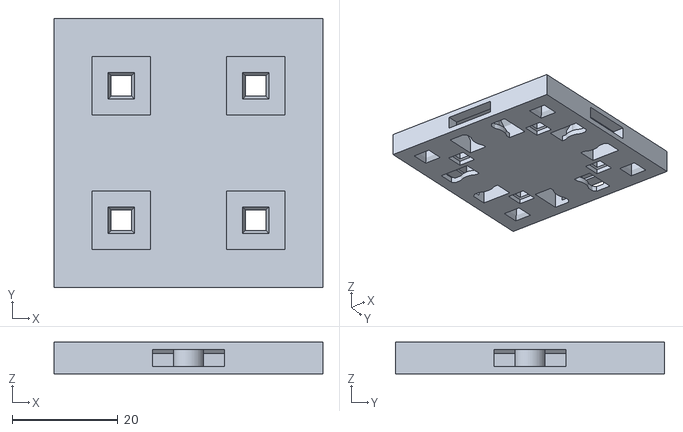
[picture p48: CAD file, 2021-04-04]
bases/plain/dragonlock,openvlex (POC)/plain#base+square.2x2.dragonlock,openvlex.stl
50.8 x 50.8 x 6.01

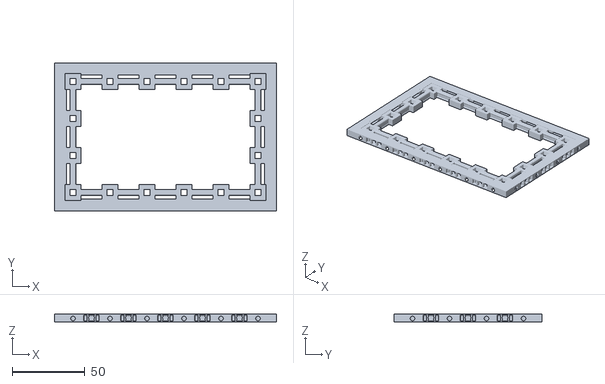
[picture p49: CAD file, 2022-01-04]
bases/plain/magnetic,openlock,openvlex+dual_parts/plain#base+square.6x4.magnetic,openlock,openvlex+border_only,upper_part.stl
152.4 x 101.6 x 5.40

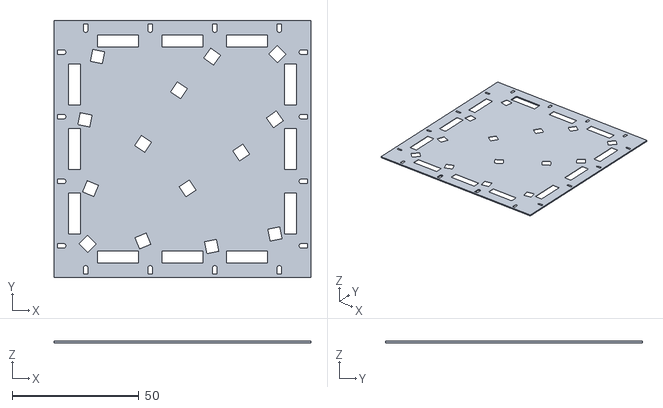
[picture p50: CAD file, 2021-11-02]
bases/plain/magnetic,openlock,openvlex+radial/plain#base+square.4x4.magnetic.openlock,openvlex+radial,lower_part.stl
101.2 x 101.2 x 0.6

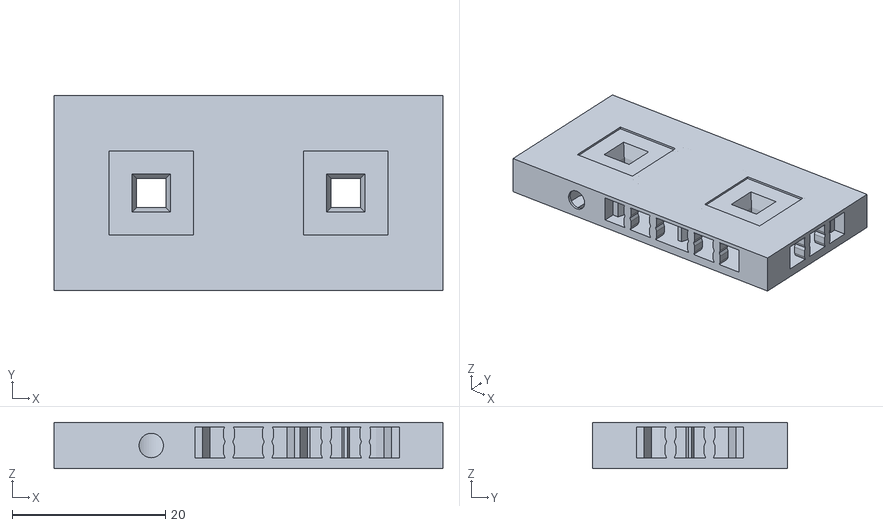
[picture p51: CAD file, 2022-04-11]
bases/plain/magnetic,openlock,openvlex+single_part/plain#base+square.2x1.magnetic,openlock,MMOOMM,openvlex+single_part.stl
50.8 x 25.4 x 6.01

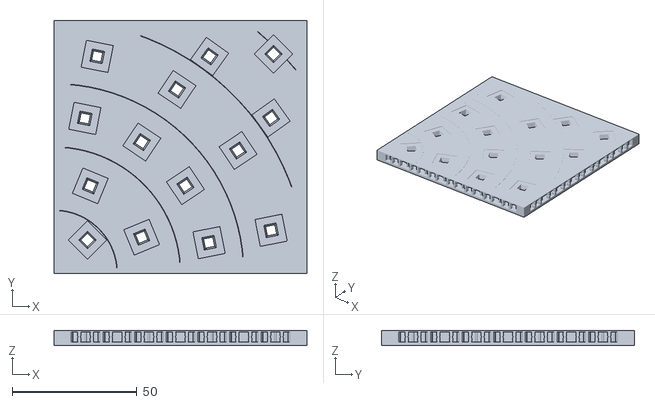
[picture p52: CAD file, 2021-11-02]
bases/plain/openlock,openflex+radial/plain#base+square.4x4.openlock,openvlex+radial.stl
101.6 x 101.6 x 6.01

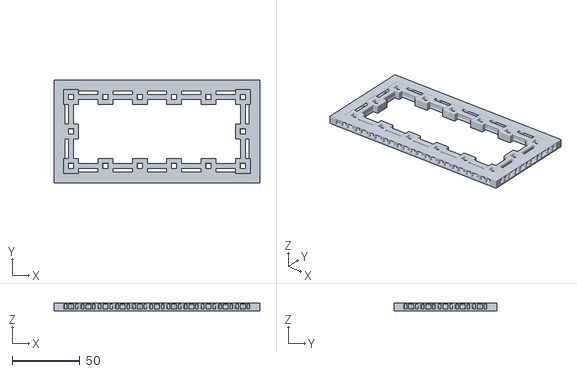
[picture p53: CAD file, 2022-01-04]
bases/plain/openlock,openvlex/plain#base+square.6x3.openlock,openvlex+border_only.stl
152.4 x 76.2 x 6.01

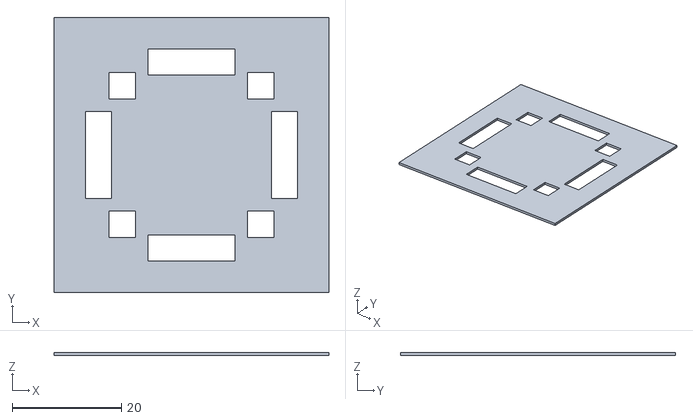
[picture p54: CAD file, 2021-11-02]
bases/plain/POC/base.plain.square.inch.2x2.magnetic.openlock.openvlex_lower.stl
50.4 x 50.4 x 0.6

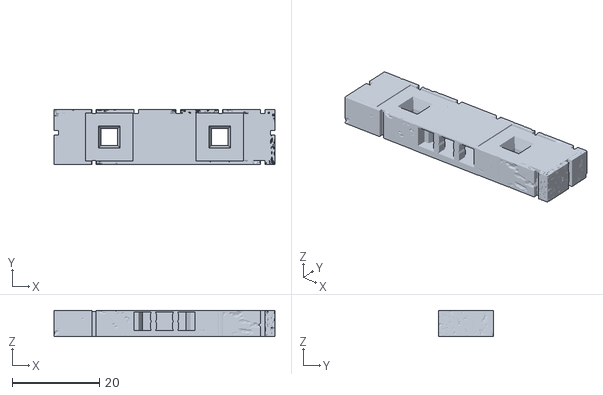
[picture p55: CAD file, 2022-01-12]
bases/separate_wall/cut_stone#base.A.openlock,openvlex.stl
50.8 x 12.7 x 6.00

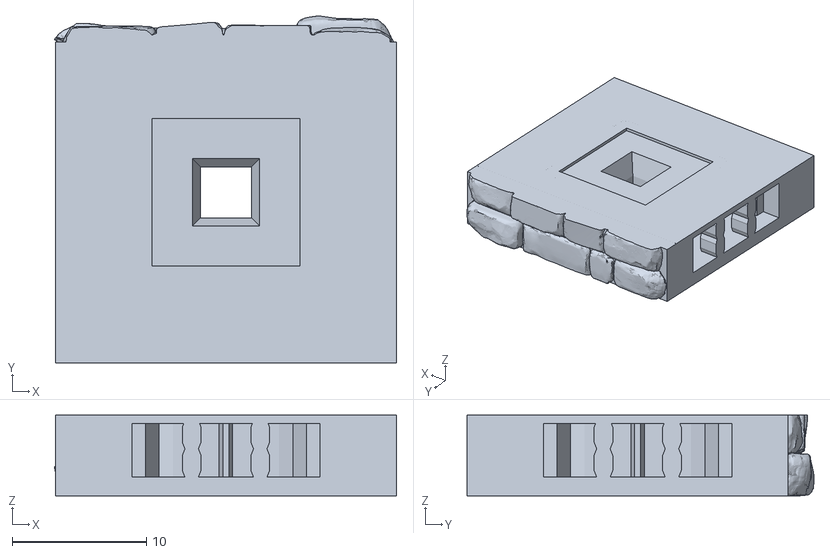
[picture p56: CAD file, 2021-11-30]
bases/sewer/sewer#base+square.1x1.openlock,openvlex+edge.stl
25.5 x 25.8 x 6.01

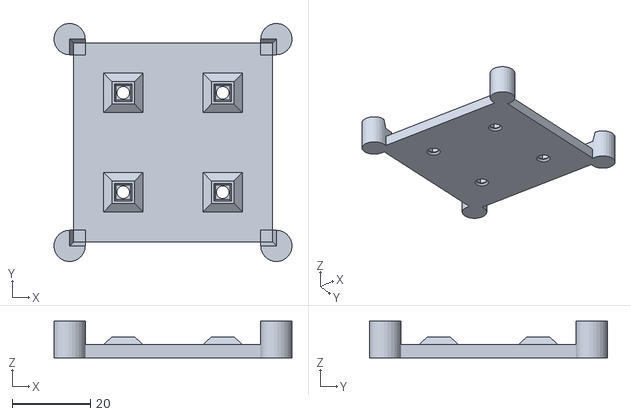
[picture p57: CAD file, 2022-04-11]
gluing-stencil/openvlex_gluing_stencil.2x2.stl
60.8 x 60.8 x 9.40

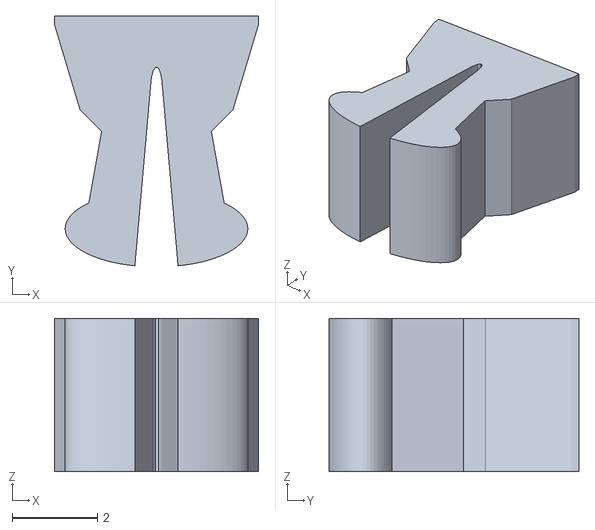
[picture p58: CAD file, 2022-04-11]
jacks/openvlex.glue_jack (v2.5.0).stl
4.80 x 5.87 x 3.60

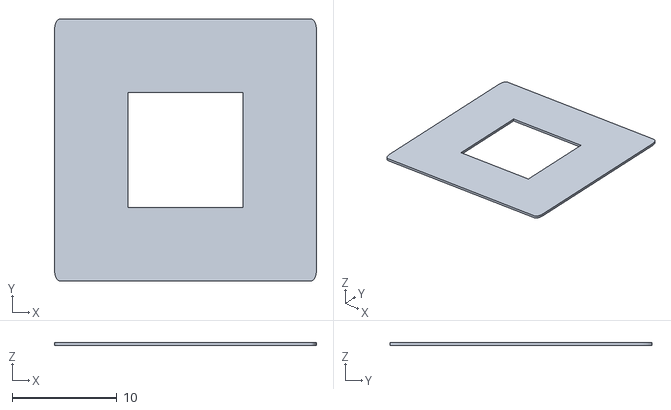
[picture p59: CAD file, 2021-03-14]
openflex1_to_openvlex2_adapter/openflex1_to_openvlex2_adapter_plate.large.1x1.stl
25.0 x 25.0 x 0.296

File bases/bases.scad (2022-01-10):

/*
 * OpenVLex Bases v2.0.4
 *
 * Credits: OpenForge 2.0
 * Original Work by Devon Jones
 * https://www.patreon.com/masterworktools
 */

/* [Base Tile Size] */
x = 2; //[1,2,3,4,5,6,7,8]
y = 2; //[1,2,3,4,5,6,7,8]

/* [Square Basis] */
// What is the size in mm of a square?
square_basis = "inch"; // [25mm:Dwarven Forge/Hirstarts, inch:OpenLOCK/Dragonlock/Dungeonworks, wyloch:Wyloch]

/* [Lock] */
// Dragonlock - connector between squares, pips on either side for stacking
// InfinityLock - connector between squares and in the middle of squares
// OpenLOCK - connector between squares
// OpenLOCK Triplex - connector between squares and in the middle of squares
lock = "triplex";// [openlock,triplex,infinitylock,dragonlock,none]

/* [Magnets] */
// Size of hole for magnet.  6 works well for 5mm buckyball style magnets.  0 to eliminate.
magnet_hole = 6.0;

/* [Priority] */
// Do you want lock or magnets to win when the two conflict
priority = "magnets"; // [lock,magnets]

/* [Shape] */
// What type of tile is this for
shape = "square"; // [square,diagonal,curved,alcove]

/* [Curved Options] */
// Options for curved, will be ignored if the tile type is not curved
// curvedconcave - concaved base instead of convex
// curvedlarge - 6x6 and 8x8 are made of 3 tiles, a, b & c
// curvedsquare - When you want a curved wall, with floors on both sides, but a square won't work
curvedconcave = "false"; // [true,false]
curvedlarge = undef; // [undef,a,b,c,d,e,f]
curvedsquare = "false"; // [true,false]

/* [Notch Options] */
// Removes a square from the tile of notch_x by notch_y
notch = "false"; // [true,false]
notch_x = 2; // [1,2,3]
notch_y = 2; // [1,2,3]

/* [Dynamic Floors] */
// Add support for dynamic floors
dynamic_floors = "false";  // [true,false]

/* [Topless] */
// remove top of openlock bays
topless = "false"; // [true, false]

/* [External] */
// Set to true if you want a side to be exteral, that side will be extended by half and have connection bays removed

external_north = "false"; // [true, false]
external_south = "false"; // [true, false]
external_east = "false"; // [true, false]
external_west = "false"; // [true, false]

/* [OpenVLex Sockets] */
// OpenVLex vertical locking sockets
ov_sockets = "square"; // [none: Disable OpenVLex, square: Standard square grid OpenVLex, radial: Radial OpenVLex sockets]
 
/* [OpenVLex Magnetic Part] */
// Which part to render for magnetic OpenVLex
ov_part = "all"; // [all, upper, lower, sockets_only, bottom_sockets]
// Cut out round "windows" on the side faces to increase the magnetic pull
ov_magnet_window = "true"; // [true, false]

/* [OpenVLex Additional Supports] */
// Add additional supports? (Recommended for OpenVLex triplex)
ov_additional_stability_bars = "true"; // [true, false]
// notch out unneeded parts of the base tile to save material and print time
ov_material_saving = "checker"; // [none: none - massive base without any center notches, whole_center: whole center notch, checker: checkerboard holes]

/*
 * Dragonlock connection bay
 */
module dragonlock_nub(square_basis) {
    translate([0,-square_basis/2,0]) {
        hull() {
            translate([3.92,16.62,-1]) cube([4.85,4.85,1]);
            translate([3.92+.74,16.62+.74,0]) cube([4.85-.74*2,4.85-.74*2,1.03]);
        }
        translate([3.92+.74,16.62+.74,1]) cube([4.85-.74*2,4.85-.74*2,4.21]);
    }
}
module dragonlock_positive() {
    translate([0,-7.8418,0.4]) cube([2,7.8418*2,5.6]);
    //translate([3.92-1,16.62-1,0.4]) cube([6.85,6.85,5.6]);
    //translate([3.92-1,-16.62-1-4.85,0.4]) cube([6.85,6.85,5.6]);
}

module dragonlock_negative(priority="lock") {
    difference() {
        translate([-1,-6.8418,1.3695]) cube([5.1,6.8418*2,3.225]);
    }
    difference() {
        hull() {
            if(priority == "lock") {
                translate([3.17,-12.7,-1]) cube([8.512,12.71*2,6]);
                translate([3.145,-12.7,-1]) cube([8.512,12.71*2,6.206]);
            } else {
                translate([3.17,-9,-1]) cube([8.512,9*2,6]);
                translate([3.145,-9,-1]) cube([8.512,9*2,6.206]);
            }
        }
        translate([10.29,-12.8,5.206]) rotate([0,45,0]) cube([8.512,12.8*2,6.206]);
        translate([3,-3.9095,-1.1]) cube([10,3.9095*2,2.4695]);
        translate([3,-4.7685,-1.1]) rotate([0,0,39.15]) cube([5,5,2.4695]);
        mirror([0,1,0]) translate([3,-4.7685,-1.1]) rotate([0,0,39.15]) cube([5,5,2.4695]);
        translate([7,-2.12,-1]) cube([5,2.12*2,10]);
        translate([8.069,0,-1]) cylinder(10,2.815,2.811,$fn=50); 
        translate([8.069,0,-1.1]) cylinder(2.4695,4.62,4.62,$fn=50);
    }
}

module dragonlock_interior(north=true,south=true,east=true,west=true,center=true) {
    module edge() {
        difference() {
            hull() {
                translate([3.17,-12.67,-1]) cube([8.512,12.67*2,6]);
                translate([3.145,-12.7,-1]) cube([8.512,12.67*2,6.206]);
            }
            translate([10.29,-12.8,5.206]) rotate([0,45,0]) cube([8.512,12.8*2,6.206]);
        }
    }
    
    translate([0,25.4,0]) {
        if(center) {
            difference() {
                translate([12.7,-12.7,-1]) cube([50.8-12.7*2,50.8-12.7*2,6.206]);
                translate([25.4,0,0]) rotate([0,0,45]) translate([-.75,-30,-2]) cube([1.5,60,20]);
                translate([25.4,0,0]) rotate([0,0,-45]) translate([-.75,-30,-2]) cube([1.5,60,20]);
            }
        }

        if (!west) {
            edge();
        }
        if (!south) {
            translate([25.4,-25.4,0]) rotate([0,0,90]) edge();
        }
        if (!east) {
            translate([50.8,0,0]) rotate([0,0,180]) edge();
        }
        if (!north) {
            translate([25.4,25.4,0]) rotate([0,0,270]) edge();
        }
        dragonlock_nub(square_basis);
        translate([25.4,-25.4,0]) rotate([0,0,90]) dragonlock_nub(square_basis);
        translate([50.8,0,0]) rotate([0,0,180]) dragonlock_nub(square_basis);
        translate([25.4,25.4,0]) rotate([0,0,270]) dragonlock_nub(square_basis);
    }
}

/*
 * Infinity Lock connection bay
 */
module infinitylock_positive() {
    translate([0,-6.6,0.4]) cube([2,6.6*2,5.6]); 
}

module infinitylock_negative() {
    translate([-1,-5.6,1.4]) cube([2.6,5.6*2,4.2]);

    hull() {
        translate([0,-3.83,1.4]) cube([1.6,3.83*2,4.2]);
        translate([0,-3.36,1.4]) cube([2.15,3.36*2,4.2]);
    }
    translate([0,-3.36,1.4]) cube([2.8,3.36*2,4.2]);
    hull() {
        translate([2.7,-3.36,1.4]) cube([2.7,3.36*2,4.2]);
        translate([3.84,-3.83,1.4]) cube([1,3.83*2,4.2]);
    }
    translate([4.8,-3.83,-1]) cube([3.44,3.83*2,6.6]);
}

/*
 * Openlock connection bay
 */
module openlock_chamber(buffer=0) {
    add = topless == "true" ? 10 : 0;
    translate([-buffer,-7,1.4]) cube([2+buffer,7*2,4.2+add]);
    hull() {
        translate([0,-6,1.4]) cube([2,6*2,4.2+add]);
        translate([3+0.01,-5,1.4]) cube([2,5*2,4.2+add]);
    }
    hull() {
        translate([5,-5,1.4]) cube([1,5*2,4.2+add]);
        translate([6,-5,1.4]) cube([1,5*2,4.7]);
    }
    translate([6,-6.4,-1]) cube([4.7,6.4*2,7.1]);
}

module openlock_supports() {
    module support() {
        translate([-1.1,2.05,1.2]) cube([3.1,1,4.6]);
        hull() {
            translate([-1.1,2.05,1.4]) cube([3.1,1,2.1]);
            translate([-1.1,2.05-.2,1.9]) cube([3.1,1.4,1.1]);
        }
        hull() {
            translate([-1.1,2.05,3.5]) cube([3.1,1,2.1]);
            translate([-1.1,2.05-.2,4.0]) cube([3.1,1.4,1.1]);
        }
    }
    if (topless != "true") {
        support();
        mirror([0,1,0]) support();
    }
}

module openlock_positive() {
    translate([0,-8,0.4]) cube([2,16,5.6]); 
}

module openlock_negative(supports=true) {
    difference() {
        openlock_chamber(1);
        if(supports) {
            openlock_supports();
        }
    }
}

/*
 * Magnets
 */
module magnet_positive(magnet_hole=5.5) {
    if (magnet_hole > 0) {
        translate([magnet_hole/2+1,0,0]) cylinder(.41,magnet_hole/2+1-.25,magnet_hole/2+1, $fn=100);
        translate([magnet_hole/2+1,0,0.4]) cylinder(5.6,magnet_hole/2+1,magnet_hole/2+1, $fn=100);
    }
}

module magnet_negative(magnet_hole=5.5) {
    if (magnet_hole > 0) {
        if (ov_sockets == "none") {
            translate([1,-magnet_hole/2,1]) cube([magnet_hole/2,magnet_hole,8]);
            translate([1,-0.9,-2]) cube([magnet_hole/2,1.8,10]);
            translate([magnet_hole/2+1,0,1]) cylinder(8,magnet_hole/2,magnet_hole/2, $fn=100);
            translate([magnet_hole/2+1,0,-2]) cylinder(10,.9,.9,$fn=50);
        } else {
            // handled later
        }
    }
}
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

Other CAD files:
socket_negatives/openvlex.bottom_socket_negative.square.1x1.large.stl
stairs_and_risers/cut_stone/square/cut_stone_stairs.square.inch.riser.2x1x1.0.openvlex.stl
stairs_and_risers/dungeon_stone/curved/dungeon_stone_stairs.curved.inch.riser.1+2x45°x0.25.openvlex.radial.stl
stairs_and_risers/dungeon_stone/square/dungeon_stone_stairs.square.inch.riser_base.1x1x0.5.NS.openvlex.top_and_bottom.stl
bases/dungeon_stone/dungeon_stone#base+square.1x1.openlock,openvlex+corner.stl
bases/dungeon_stone/dungeon_stone#base+square.1x1.openlock,openvlex+edge.stl
bases/dungeon_stone/dungeon_stone#base+square.2x1.openlock,openvlex+corner-left.stl
bases/dungeon_stone/dungeon_stone#base+square.2x1.openlock,openvlex+corner-right.stl
bases/dungeon_stone/dungeon_stone#base+square.2x1.openlock,openvlex+edge.stl
bases/dungeon_stone/dungeon_stone#base+square.2x2.openlock,openvlex+corner.stl
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

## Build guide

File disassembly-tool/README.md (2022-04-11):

# OpenVLex Disassembly Tool

## About

The OpenVLex Disassembly Tool makes it easy to **remove tiles** from an OpenVLex base and is also convenient for removing tiles from the gluing stencil with freshly glued OpenVLex jacks.

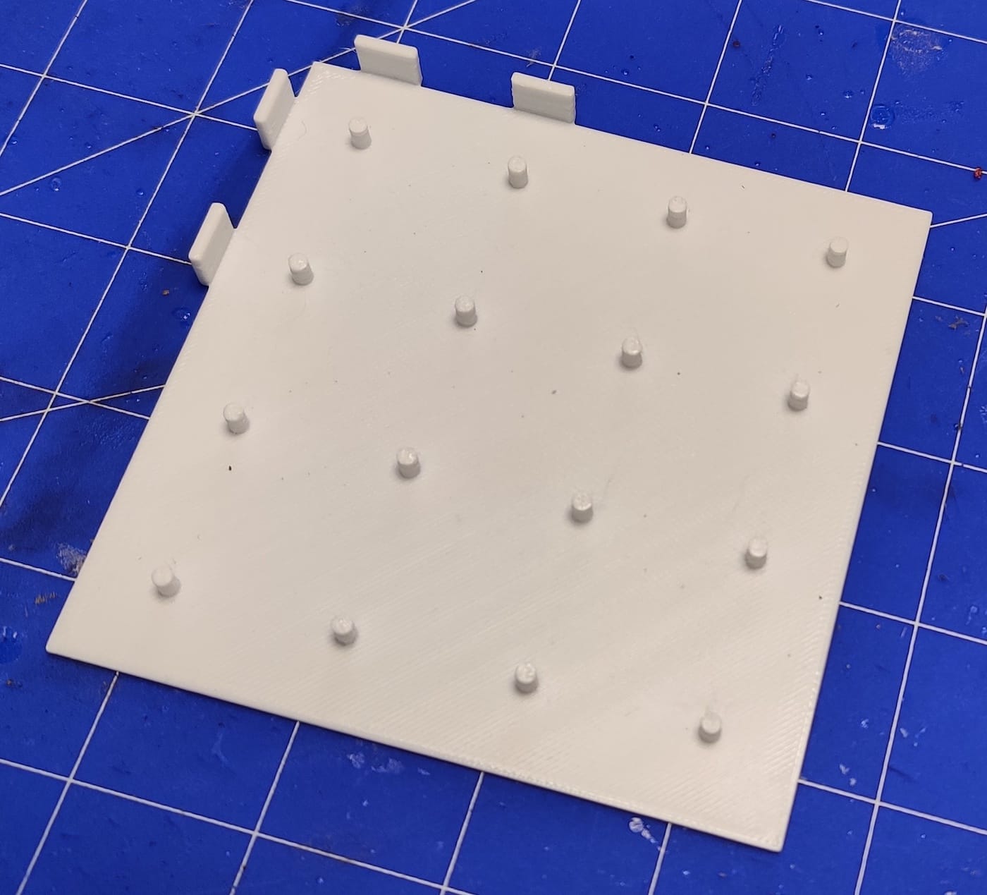
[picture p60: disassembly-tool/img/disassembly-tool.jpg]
Disassembly Tool
   
	
## Usage

### 1. Align tile base or stencil

   Disassembly Tool - Align tile base or stencil
   
### 2. Press down the corners
   
   Disassembly Tool - Press down the corners

## Printing Notes

- Material: PLA or PETG
- Nozzle: 0.4 mm
- Layer height: 0.10 mm or 0.15 mm
- Fill Density: 10% to 15%

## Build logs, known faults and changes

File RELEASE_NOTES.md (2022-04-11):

## OpenVLex 2.5.0

- new improved OpenVLex jacks which now look like "teeth" and can be printed sideways to be much stronger
- improved gluing stencils
- additional plain risers

## OpenVLex 2.4.1

- reduced wall thickness of stackable plain riser parts
- added some more stackable riser system compatible bases 

## OpenVLex 2.4.0

- new flexible riser system: stack risers of any height (platform, low, medium, high) by snapping together just a few simple parts. No need to print every different height in advance.

  Find the new riser parts and instructions here: `stairs_and_risers/plain/README.md`

- improved OpenVLex bases:
	- new geometry with holes for saving material
	- new vertical locking mechanism bars, ready for the new flexible riser system (see above)

- improved magnetic OpenVLex bases: added round "windows" on the sides to make attraction of spheric magnets stronger

- improved OpenVLex jacks: the new jack geometry now uses a flexible bridge for making the jack pins more durable and much less prone for breaking with brittle PLA

## OpenVLex 2.3.1

- revised the paused printing instructions and added a hint to only try this with brass nozzles

## OpenVLex 2.3.0

- added magnetic OpenVLex bases as single printable parts for printing with a pause and placing magnets directly on the printer (detailed instructions included)

## OpenVLex 2.2.0

- OpenVLex plain bases now have new magnet holes based on Devon Jones' new "flex" OpenForge bases to support both magnetic spheres and discs
- naming of OpenVLex bases now follows Devon's new OpenForge naming scheme
- added a new 4x4 gluing stencil
- added a disassembly tool for easier separating tiles from there bases
- dungeon stone risers with integrated base upper floor level

## OpenVLex 2.1.0

This time it's all about _dungeon stone_ corner and edge bases. These special OpenVLex bases make it possible to re-use your wall-on-tile parts (walls, floors, ...) on the outside of your dungeons or buildings without having ugly holes in the foundation.

- added dungeon stone corner and edge bases
- added new bottom socket negatives
- added storage base clip
- added double jack

## OpenVLex 2.0.8

Vertically combining curved parts? Radial OpenVLex joints make it possible!

Highlights in this release:

- new square bases with radial OpenVLex sockets
- new curved bases with radial OpenVLex sockets
- lots of (curved and radial!) dungeon stone risers, stairs and platforms
- new jack variants
- improved magnetic bases

## OpenVLex 2.0.7

- slight socket improvement (wider top opening for easier plugging)
- radial bases and stairs! This is the first POC draft of the OpenVLex radial stair construction kit.
- replaced bases with additional support bars and replaced them by additionally braced triplex bases
- added connector sockets negatives that can be used for custom riser kitbashing

## OpenVLex 2.0.6

- revised docs
- added connector negative

## OpenVLex 2.0.5

This is the first public release of OpenVLex 2.x

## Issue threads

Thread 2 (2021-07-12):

Open for requests?

Gathaeryx, 2021-07-12:
Hi! I really love your solution for the risers, it seems the cleanest way to create spiraling stairs and the sort. But I was wondering if it would be possible for you to add 'half-steps' on top of the current slabs, so the stairs would look somewhat more realistic than the large stone OpenForge slabs.

manolitto, 2021-07-12:
Yeah, sure. Happy about any feedback and suggestions for improvement.

So, if I got you right you want parts like [this](https://github.com/manolitto/openvlex2/blob/main/stairs_and_risers/dungeon_stone/curved/dungeon_stone_stairs.curved.inch.riser.1%2B2x45%C2%B0x0.5.openvlex.radial.stl) with half the height?

manolitto, 2021-07-12:
> Hi! I really love your solution for the risers, it seems the cleanest way to create spiraling stairs and the sort. But I was wondering if it would be possible for you to add 'half-steps' on top of the current slabs, so the stairs would look somewhat more realistic than the large stone OpenForge slabs.

@Gathaeryx  Take a look at this [quick POC](https://github.com/manolitto/openvlex2/blob/main/stairs_and_risers/dungeon_stone/curved/dungeon_stone_stairs.curved.inch.riser.1%2B2x45%C2%B0x0.25.openvlex.radial.st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). Is it what you are looking for?

Gathaeryx, 2021-07-16:
Sorry for the late reply, but thanks for the quick response! I did actually intend a bit different step: What I meant was if you could design a step with half the depth and half the height, so it could be place on the one you linked first. I guess that results in the design from your second post, but with only half the angle?

Or maybe even those two joined together, resulting in a double step to be pinned on the base. My goal is to get more steps covering the same height, like 'real' winding stairs. I do like Devon's approach with the ~1 inch sized steps, so you can place a mini on them, but I've found that it looks a bit wonky when I've put a lot of them side by side.

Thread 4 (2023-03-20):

Struggling to get the tiny supports out of the bases

CptFry, 2023-03-20:
Hey there!

I love the bases, but I'm really struggling to get the tiny extra supports out of the bases. Most of the time the top layer is breaking in half when I snip them out.

Is there some secret technique I'm missing?

manolitto, 2023-03-20:
Hi,
To remove supports from the bases I use pliers with 4 mm wide shoes. I firmly grab the support bars and then twist them out. This is the one I use:
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

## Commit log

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2021-03-14 added triplex with additional supports
    [base.plain.square.inch.1x1.magnetic.openlock.openvlex_with_supports.stl, base.plain.square.inch.2x1.magnetic.openlock.openvlex_with_supports.stl, base.plain.sq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]
2021-03-14 added openflex1 to openvlex2 adapter
    [openflex1_to_openvlex2_adapter_plate.large.1x1.stl, openflex1_to_openvlex2_adapter_plate.large.2x1.stl, openflex1_to_openvlex2_adapter_plate.large.2x2.stl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]
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2021-03-17 fixed wrong triplex filenames
    [base.plain.square.inch.1x1.triplex.openvlex.stl, base.plain.square.inch.1x1.triplex.openvlex_with_supports.stl, base.plain.square.inch.2x1.triplex.openvlex.stl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]
2021-03-17 upgraded bases: widened socket diameter on top to 5 mm
    [base.plain.square.inch.1x1.magnetic.openlock.openvlex_lower.stl, base.plain.square.inch.1x1.magnetic.openlock.openvlex_upper.stl, base.plain.square.inch.1x1.tr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]
2021-03-20 newly generated bases (and new radial ones)
    [base.plain.square.inch.1x1.magnetic.openlock.openvlex_lower.stl, base.plain.square.inch.1x1.magnetic.openlock.openvlex_upper.stl, base.plain.square.inch.1x1.tr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]
2021-03-20 added new radial connector socket negatives
    [openvlex.connector_negative.curved.2x2.radial.stl, openvlex.connector_negative.curved.4x4.radial.stl, openvlex.connector_negative.square.1x1.square.stl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]
2021-03-20 added new stairs with radial sockets
    [base.plain.square.inch.2x2.triplex.openvlex.radial.stl, base.plain.square.inch.4x4.triplex.openvlex.radial.stl, cut_stone_stairs.inch.2x1x0.5.riser.openvlex.st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]
2021-03-21 added radial 1x1 negative connector socket
    [openvlex.connector_negative.curved.1x1.radial.stl]
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2021-03-27 new stairs and risers
    [_lowpoly-dungeon_stone_stairs.curved.inch.platform.1+2x45°.A.stl, _lowpoly-dungeon_stone_stairs.curved.inch.platform.1+2x45°.B.stl, _lowpoly-dungeon_stone_stai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]
2021-03-27 removed the outdated lowpoly stairs
    [_lowpoly-dungeon_stone_stairs.curved.inch.platform.1+2x45°.A.stl, _lowpoly-dungeon_stone_stairs.curved.inch.platform.1+2x45°.B.stl, _lowpoly-dungeon_stone_stai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]
2021-03-28 first draft of curved OVL bases
    [bases.scad]
2021-03-29 added curved radial triplex bases
    [base.plain.curved.inch.2x2.triplex.radial.openvlex.stl, base.plain.curved.inch.3x3.triplex.radial.openvlex.stl, base.plain.curved.inch.4x4.triplex.radial.openv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]
2021-03-29 added curved radial triplex braced bases
    [base.plain.curved.inch.2x2.triplex.radial.braced.openvlex.stl, base.plain.curved.inch.3x3.triplex.radial.braced.openvlex.stl, base.plain.curved.inch.4x4.triple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]
2021-03-31 added two new 4x dungeon stone risers
    [dungeon_stone_stairs.curved.inch.riser.4x45°x0.5.openvlex.radial.stl]
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2021-04-04 added dragonlock 2x2 base
    [base.plain.square.inch.2x2.dragonlock.openvlex.stl, bases.scad]
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2021-04-05 added dungeon stone bases
    [base.dungeon_stone.corner.square.inch.2x2.triplex.openvlex.stl, base.dungeon_stone.edge.A.square.inch.2x2.triplex.openvlex.stl, base.dungeon_stone.edge.B.squar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]
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2021-04-06 renamed jack variants and added jack slicer images
    [openvlex.connector_negative.curved.1x1.radial.stl, openvlex.connector_negative.curved.2x2.radial.stl, openvlex.connector_negative.curved.4x4.radial.stl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]
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2021-04-06 fixed bottom socket negatives
    [bases.scad, openvlex.bottom_socket_negative.curved.1x1.radial.stl, openvlex.bottom_socket_negative.curved.1x1.radial.with_alignment_helper.stl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]
2021-04-06 added new cut stone raisers with bottom socket holes
    [cut_stone_stairs.square.inch.2x1x0.5.riser.openvlex.stl, cut_stone_stairs.square.inch.2x1x1.0.riser.openvlex.stl, cut_stone_stairs.square.inch.2x2x0.5.riser.op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]
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2021-04-06 added new towne raisers with bottom socket holes
    [towne_stairs.square.inch.1x1x1.0.riser.openvlex.stl, towne_stairs.square.inch.2x1x1.0.riser.openvlex.stl, towne_stairs.square.inch.2x2x1.0.riser.openvlex.stl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]
2021-04-06 added new dungeon stone raisers with bottom socket holes
    [dungeon_stone_stairs.square.inch.riser.1x1x0.5.openvlex.stl, dungeon_stone_stairs.square.inch.riser.2x1x0.5.openvlex.stl, dungeon_stone_stairs.square.inch.rise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]
2021-04-06 fixed dungeon stone risers
    [dungeon_stone_stairs.square.inch.riser.1x1x0.3.openvlex.stl, dungeon_stone_stairs.square.inch.riser.1x1x0.5.openvlex.stl, dungeon_stone_stairs.square.inch.rise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]
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2021-04-16 added more dungeon stone bases - sizes and variants
    [base.dungeon_stone.corner.square.inch.4x1.A.triplex.openvlex.stl, base.dungeon_stone.corner.square.inch.4x1.B.triplex.openvlex.stl, base.dungeon_stone.edge.squ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]
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2021-11-02 improved bases generator: new magnet holes based on Devons new "flex" holes
    [bases.scad]
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2021-11-02 rebuilt plain bases to follow Devons new "flex" magnet holes, renamed all base parts to follow Devons new naming scheme
    [base.plain.curved.inch.2x2.triplex.radial.braced.openvlex.stl, base.plain.curved.inch.2x2.triplex.radial.openvlex.stl, base.plain.curved.inch.3x3.triplex.radia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]
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2021-11-16 added single part plain bases for printing with pause for magnet placement
    [plain#base+square.1x1.magnetic,openlock+openvlex.stl, plain#base+square.2x1.magnetic,openlock+openvlex.stl, plain#base+square.2x2.magnetic,openlock+openvlex.st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]
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2022-01-03 added new stackable riser system compatible plain bases v2.4
    [plain#base+square.1x1.magnetic,openvlex+single_part.stl, plain#base+square.1x1.openlock,openvlex.stl, plain#base+square.2x1.magnetic,openlock,openvlex+single_p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]
2022-01-03 reduced wall thickness of stackable plain riser parts
    [plain#riser+square,interlayer_half.2x1.openvlex.stl, plain#riser+square,interlayer_half.2x2.openvlex.stl, plain#riser+square,platform.2x1.openvlex.stl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]
2022-01-03 reduced wall thickness for backwards compatible plain risers
    [plain#riser+square,interlayer_half.2x2.openvlex,backwards_compatible.stl, plain#riser+square,platform.2x2.openvlex,backwards_compatible.stl]
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
